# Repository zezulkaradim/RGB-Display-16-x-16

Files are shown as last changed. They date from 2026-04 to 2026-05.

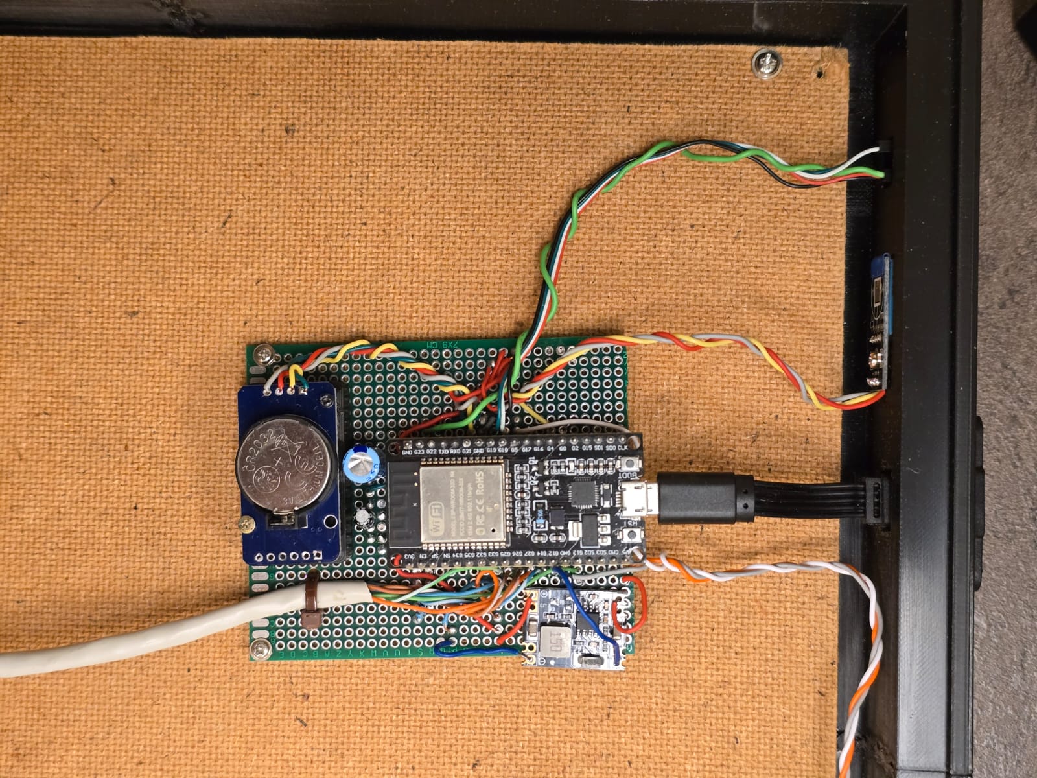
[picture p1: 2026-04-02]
Images/1000010734.jpg

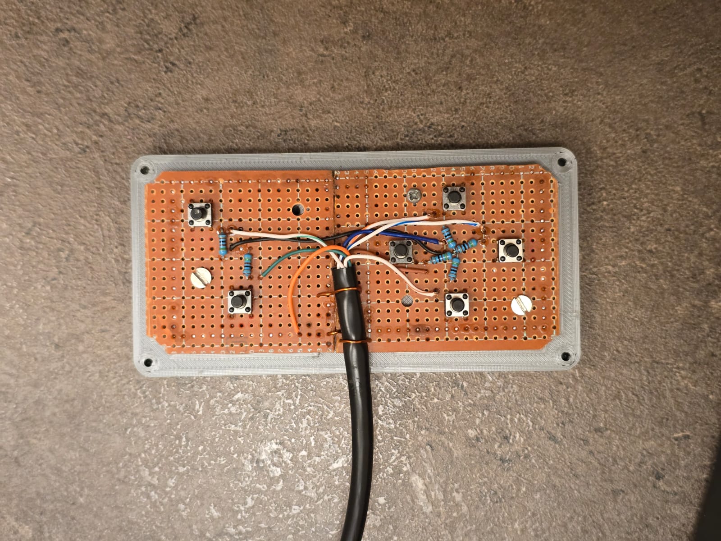
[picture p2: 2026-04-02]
Images/1000010737.jpg

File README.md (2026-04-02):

# RGB-Display-16-x-16

Tato práce se zabývá návrhem a realizací multifunkčního RGB LED displeje o rozměru 16 × 16 pixelů řízeného mikrokontrolerem ESP32. Cílem práce bylo vytvořit samostatné zobrazovací zařízení s více provozními režimy a vlastním způsobem ovládání. Displej je tvořen z adresovatelných LED diod typu WS2812B uspořádaných do čtvercové matice. Součástí řešení je displejové menu, které je ovládáno pomocí externího kabelového ovladače a umožňuje přepínání jednotlivých funkcí zařízení. Implementovány byly digitální hodiny synchronizované přes Wi-Fi s ukládáním času do modulu reálného času DS3231, zobrazení teploty a vlhkosti z čidla DHT11, sada dekorativních animací, hra Had s zobrazením skóre a VU metr využívající digitální mikrofon INMP441. Další funkcí je možnost vzdáleného kreslení na displej prostřednictvím webového rozhraní vytvořeného na platformě ESP32. Výsledkem je vizuálně atraktivní a interaktivní zařízení určené především k dekorativnímu zobrazení, které lze dále rozšiřovat o nové režimy a funkce.

This thesis describes the design and implementation of a multifunctional 16 x 16 RGB LED display controlled by an ESP32 microcontroller. The objective was to develop a standalone display device featuring multiple operating modes and a custom control system. The display consists of WS2812B addressable LEDs arranged in a square matrix. The solution includes a display menu operated via an external wired controller, allowing users to switch between various functions. Implemented features include digital clocks synchronized over Wi-Fi with time storage in a DS3231 real-time clock module, temperature and humidity display using a DHT11 sensor, a set of decorative animations, the game Snake with score tracking, and a VU meter utilizing an INMP441 digital microphone. Additionally, the device supports remote drawing via a web interface. The result is a visually attractive device designed for decorative purposes, with potential for further expansion of functions.

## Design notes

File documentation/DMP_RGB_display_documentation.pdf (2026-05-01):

# Střední Průmyslová Škola Elektrotechnická Ječná

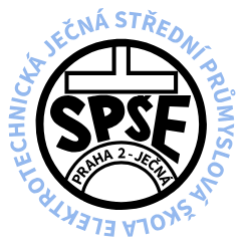
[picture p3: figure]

# DLOUHODOBÁ MATURITNÍ PRÁCE

# RGB displej 16x16

# 2026 Radim Žežulka

# Střední Průmyslová Škola Elektrotechnická Ječná

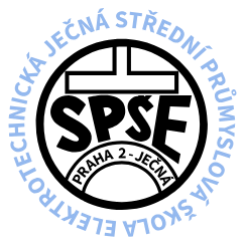
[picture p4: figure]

# DLOUHODOBÁ MATURITNÍ PRÁCE

## RGB displej 16x16

## RGB display 16x16

Autor: | Radim Žežulka
Třída: | E4
Obor: | Elektrotechnika – Elektronické počítačové systémy
Škola: | SPŠE Ječná, Ječná 30, 120 00 Praha 2
Vedoucí práce: | Jan Molič

Oponent práce: Bc. Marek Lavička

Praha, 5.4.2026

## Prohlášení

Prohlašuji, že jsem dlouhodobou maturitní práci (dále jen „DMP“) vypracoval samostatně a

použil jsem pouze prameny a literaturu uvedené v seznamu bibliografických záznamů.

Prohlašuji, že tištěná verze a elektronická verze DMP jsou shodné.

Nemám závažný důvod proti zpřístupňování této práce v souladu se zákonem č. 121/2000 Sb.,

o právu autorském, o právech souvisejících s právem autorským a o změně některých zákonu

(autorský zákon) ve znění pozdějších předpisů.

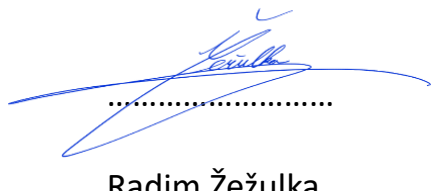
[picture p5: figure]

V Praze dne 7. 4. 2026 | |
| Radim Žežulka

## Poděkování

Chtěl bych poděkovat panu Janu Moličovi za odborné vedení mé maturitní práce. Dále děkuji

Ing. Mgr. Vladimíru Váňovi, CSc., za poskytnutí technických znalostí v oblasti mikroprocesorů

a Ing. Janě Exnerové spolu s Ing. Peterem Budaiem za poskytnutí všeobecných technických

znalostí v oblasti elektrotechniky.

Mé poděkování patří také Mgr. Jindřišce Mrázové za kontrolu jazykové správnosti textu.

Děkuji svému kamarádovi Martinu Loskotovi za pomoc při řešení problémů, na které jsem

v průběhu práce narazil. V neposlední řadě děkuji své rodině za trpělivost a všestrannou

podporu po celou dobu mého studia.

## Anotace

Tato práce se zabývá návrhem a realizací multifunkčního RGB LED displeje o rozměru

16 × 16 pixelů řízeného mikrokontrolerem ESP32. Cílem práce bylo vytvořit samostatné

zobrazovací zařízení s více provozními režimy a vlastním způsobem ovládání. Displej je tvořen

z adresovatelných LED diod typu WS2812B uspořádaných do čtvercové matice. Součástí řešení

je displejové menu, které je ovládáno pomocí externího kabelového ovladače a umožňuje

přepínání jednotlivých funkcí zařízení. Implementovány byly digitální hodiny synchronizované

přes Wi-Fi s ukládáním času do modulu reálného času DS3231, zobrazení teploty a vlhkosti

z čidla DHT11, sada dekorativních animací, hra Had s zobrazením skóre a VU metr využívající

digitální mikrofon INMP441. Další funkcí je možnost vzdáleného kreslení na displej

prostřednictvím webového rozhraní vytvořeného na platformě ESP32. Výsledkem je vizuálně

atraktivní a interaktivní zařízení určené především k dekorativnímu zobrazení, které lze dále

rozšiřovat o nové režimy a funkce.

## Klíčová slova

ESP32, senzory, WS2812B, LED displej, dekorativní osvětlení

## Abstract

This thesis describes the design and implementation of a multifunctional 16 x 16 RGB LED

display controlled by an ESP32 microcontroller. The objective was to develop a standalone

display device featuring multiple operating modes and a custom control system. The display

consists of WS2812B addressable LEDs arranged in a square matrix. The solution includes

a display menu operated via an external wired controller, allowing users to switch between

various functions. Implemented features include digital clocks synchronized over Wi-Fi with

time storage in a DS3231 real-time clock module, temperature and humidity display using

a DHT11 sensor, a set of decorative animations, the game Snake with score tracking,

and a VU meter utilizing an INMP441 digital microphone. Additionally, the device supports

remote drawing via a web interface. The result is a visually attractive device designed

for decorative purposes, with potential for further expansion of functions.

## Keywords

ESP32, sensors, WS2812B, LED display, decorative lighting

## Zadání

Cílem projektu je vytvořit interaktivní 16×16 RGB displej založený na adresovatelných LED

diodách typu WS2812B, řízený mikrokontrolerem ESP32. Projekt má za úkol propojit

zobrazovací plochu s různými senzory a ovládacími prvky tak, aby bylo možné využít displej

k animacím, vizualizacím i jednoduchým hrám.

Součástí zadání je implementace měření teploty a vlhkosti, jejichž aktuální hodnoty bude

displej zobrazovat v reálném čase. Dalším požadavkem je integrace modulu reálného času

(RTC), který umožní zobrazení přesného času a případných časových animací. Pro ovládání

displeje a jeho režimů má být navržen a realizován vlastní ovladač umožňující intuitivní

interakci s celým systémem. Projekt zahrnuje také vytvoření jednoduché hry – konkrétně hry

Had – která bude plně zobrazována na RGB matici a ovládána navrženým ovladačem.

Dále je součástí zadání pokus o implementaci mikrofonu pro vytvoření VU metru reagujícího

na zvukovou intenzitu, ačkoliv tato funkce představuje volitelné rozšíření.

V průběhu zpracování maturitní práce se žák řídí dalšími pokyny vedoucího práce dle potřeby.

## Obsah

8 Bibliografie | Chyba! Záložka není definována.

## 1 Úvod

Při hledání inspirace na internetu mě zaujaly projekty pracující s RGB maticemi, které dokážou

kombinovat funkci informačního panelu a estetického doplňku. Rozhodl jsem se proto vytvořit

vlastní zařízení, které by sloužilo nejen jako originální dekorace do mého pokoje, ale také jako

platforma kombinující různé užitečné nástroje s volnočasovými a interaktivními prvky.

Podobné principy adresovatelných LED systémů můžeme potkávat v každodenním životě.

Od velkoplošných LED billboardů a reklamních ploch až po menší informační panely, jako jsou

například typické svítící kříže u lékáren. Všechna tato zařízení sdílejí společný základ: řízení

stovek světelných bodů pro zobrazení textu a grafiky.

Cílem mé maturitní práce je vytvořit interaktivní 16×16 RGB displej založený

na adresovatelných LED diodách typu WS2812B, řízený mikrokontrolerem ESP32. Projekt má

za úkol propojit zobrazovací plochu s různými senzory a ovládacími prvky tak, aby bylo možné

využít displej k animacím, vizualizacím i jednoduchým hrám.

Výsledné zařízení nabízí pět hlavních provozních režimů, mezi které patří:

- Informační panel: Zobrazení času, teploty a vlhkosti.
- Dekorativní animace: Sada dekoračních animací.
- Hra Had: Plnohodnotná interaktivní hra had.
- Audio vizualizace: FFT VU metr reagující na intenzitu zvuku snímanou mikrofonem.
- Vzdálené kreslení: Možnost kreslení na displej přes webovou stránku.

K ovládání celého systému byl navržen a realizován vlastní kabelový ovladač, který zajišťuje

intuitivní pohyb v menu a interakci s jednotlivými funkcemi. Celý projekt tak představuje celek

propojující hardware, nízko úrovňové programování a síťovou komunikaci.

## 2 Teoretický rozbor

## 2.1 Adresovatelné led diody WS2812b

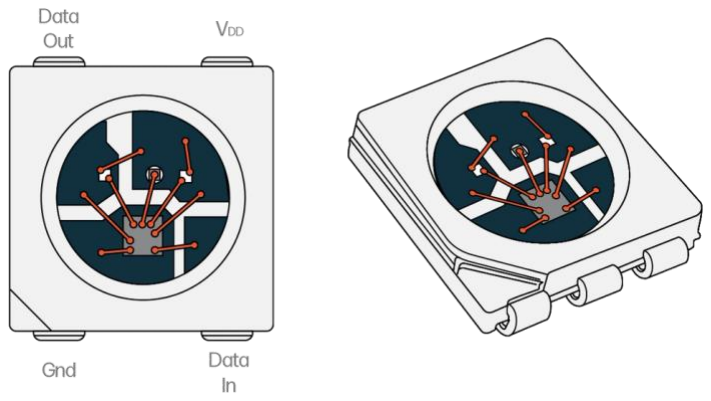
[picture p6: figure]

Obr. 1 - WS2812 LED (převzato z WORLDSEMI, 2024).

WS2812B je adresovatelná led dioda v pouzdře 5050. Každá dioda obsahuje 3 pulsně šířkové

modulátory, které ovládají LED zářiče (červený, zelený a modrý). Dále obsahuje řídící obvod s

vnitřní registrem pro záznam dat, s vnitřními hodinami pro synchronizaci s ostatními WS2812B

diodami a vyhlazujícími obvody, které se starají o konstantní barvu světla a nerušení signálu,

který posílají na Data Out.

K komunikaci používají komunikační protokol One-Wire, který funguje na principu Daisy

Chaining, kde se posílá větší objem dat, a každá dioda si uloží jen svůj podíl v našem případě

3 bajty (jeden bajt na jednu barvu) a zbytek dat pošle dál (další diodě) pomocí pinu Data Out.

Po odeslání informace do všech diod se odešle reset signál, který po krátké pauze (okolo 50 μs)

synchronizovaně nastaví nově zvolenou barvu na všech diodách najednou.

Tyto WS2812B diody lze najít např. v: podsvícení PC komponentů, v chytrých LED páscích

a v reklamních panelech [21, 41].

## 2.2 Aditivní míchání barev

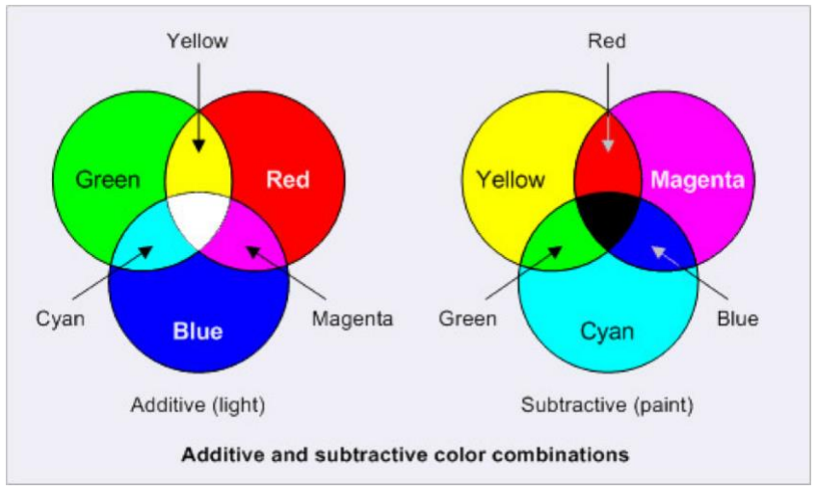
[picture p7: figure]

Obr. 2 - Aditivní a subtraktivní kombinace barev (převzato z MCAD, 2024).

V projektu je využíván princip aditivního míchání barev (RGB), který je typický pro zdroje světla

(emitory). Na rozdíl od subtraktivního míchání (CMYK), které známe z tisku na papír,

kde se barvy odrážejí a jejich sčítáním vzniká černá, u aditivního míchání se světelné toky

jednotlivých barev sčítají. Při plném výkonu všech tří složek vzniká bílé světlo, zatímco

při nulovém výkonu vzniká černá [22, 24].

V softwarové části projektu se pracuje se dvěma způsoby definice barev:

- Model RGB (Red-Green-Blue): Přímo odpovídá hardwaru diody WS2812B. Barva

je definována třemi bajty (0–255), které určují střídu PWM pro červený, zelený a modrý

čip.

- Model HSV (Hue-Saturation-Value): Tento model je výhodnější pro tvorbu plynulých

animací a duhových efektů. Barva je těmito vlastnostmi:

- Hue (Odstín): Určuje polohu barvy na barevném kruhu (0–255 ve FastLED

knihovně).

- Saturation (Sytost): Určuje čistotu barvy (od bílé po plnou barvu).
- Value (Jas): Určuje intenzitu svitu.

## 2.3 Mikrokontroler ESP32

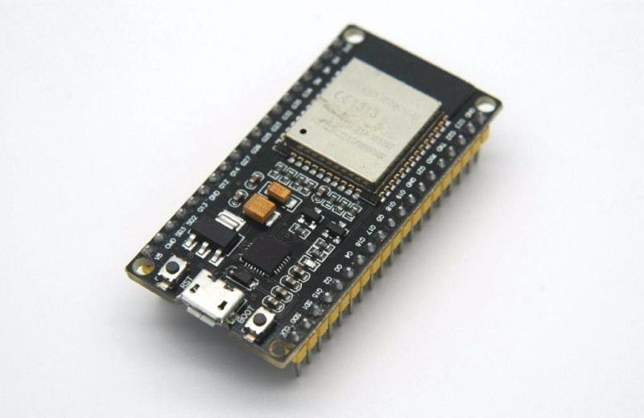
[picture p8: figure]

Obr. 3 - ESP32 Wroom (převzato z Drátek.cz, 2021).

ESP32 je výkonný 32 - bitový mikrokontroler s dvoujádrovým procesorem Xtensa LX6.

V projektu slouží jako hlavní řídicí jednotka, která v reálném čase obsluhuje výpočty pro LED

matici, čtení senzorů a síťovou komunikaci, a byl programován v prostředí Arduino IDE.

Umí komunikovat pomocí sběrnicí UART, SPI, I2C, I2S.

Je často porovnáván se známou alternativou Arduino UNO R3 (a ostatní řady). Avšak ESP32

byla jasná volba, díky osminásobné taktovací frekvenci 240 MHz, větší paměti RAM i Flash

a možnosti pracovat s WI-FI a Bluetooth bez přidaných modulů. Pracuje i na jiném provozním

napětí 3,3 V. Na Arduinech je provozní napětí 5 V, to znamená, že moduly Arduina nemusí být

kompatibilní s ESP32 a při výběru je nutné si na to dát pozor [8, 17, 18].

## 2.4 Digitální přenos zvuku – I2S

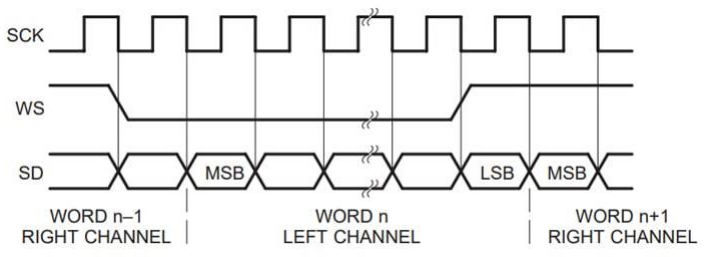
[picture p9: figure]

Obr. 4 - Sběrnice I2S (převzato z All About Circuits, 2026).

Pro realizaci funkce FFT VU metru je v projektu využit digitální mikrofon INMP441,

který s mikrokontrolerem ESP32 komunikuje pomocí protokolu I2S.Na rozdíl od běžných

analogových mikrofonů, které vyžadují předzesilovač a ADC převodník, I2S mikrofon odesílá

data již v digitální podobě, což eliminuje šum a rušení vznikající na analogových cestách [5].

I2S je sériová sběrnice navržená speciálně pro přenos digitálních audio dat mezi integrovanými

obvody. Protokol odděluje hodinový signál od datových toků, což minimalizuje časové

zkreslení. K propojení jsou zapotřebí tři hlavní vodiče:

1. SCK (Serial Clock): Bitové hodiny, které určují rychlost přenosu jednotlivých bitů.
2. WS (Word Select): Určuje, zda aktuálně přenášená data patří levému nebo pravému

zvukovému kanálu (uzemněním tohoto vodiče jsem nastavil pouze levý kanál).

3. SD (Serial Data): Samotná audio data přenášená v digitální podobě.

Po přijmutí dat mikrokontrolerem je aplikována rychlá Fourierova transformace (FFT),

která převede časový signál na frekvenční spektrum. Výsledek je poté zobrazen na displeji [6].

## 2.5 Sběrnice I2C

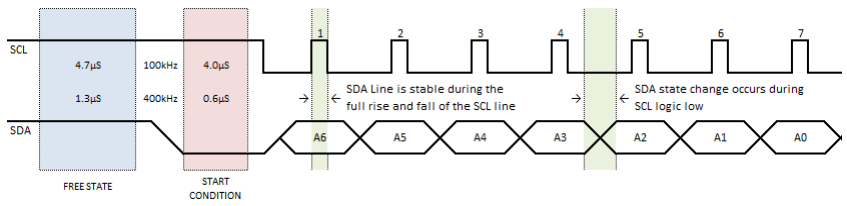
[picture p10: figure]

Obr. 5 - Sběrnice I2C (převzato z HIENYSCH, 2015).

I2C je synchronní, sériová sběrnice typu Master – Slave, která k přenosu dat využívá pouze dva

vodiče. V tomto projektu zajišťuje stabilní komunikaci mezi mikrokontrolerem ESP32 (Master)

a modulem reálného času DS3231 (Slave).

Sběrnice se skládá ze dvou signálových linek:

- SDA (Serial Data): Linka pro obousměrný přenos dat.
- SCL (Serial Clock): Hodinový signál, který určuje rychlost přenosu.

Hlavní výhodou I2C je možnost připojit na stejné dva vodiče teoreticky až 127 různých zařízení.

Každá periferie má svou pevnou 7bitovou adresu (DS3231 má adresu 0x68).

ESP32 vyšle na sběrnici signál start a následně adresu zařízení, se kterým chce mluvit.

Toto zařízení potvrdí, že signál příkaz obdrželo. Ostatní moduly na sběrnici zprávu ignorují.

Po potvrzení adresy následuje samotný přenos dat.

V mém projektu ESP32 v pravidelných intervalech dotazuje modul DS3231, na aktuální stav

vnitřních čítačů času, získaný čas zobrazuje. Při synchronizaci s NTP serverem odesílá ESP32

po I2C sběrnici nová data k zápisu do paměti modulu, čímž DS3231 seřídí na aktuální čas

(krystalový oscilátor, který udává časový průběh v DS3231 není dokonalý a po delší době

bez synchronizace s NTP serverem by se mohl odchýlit od reálného času) [4].

## 2.6 Síťové protokoly NTP, HTTP

NTP (Network Time Protocol) slouží k synchronizaci vnitřního času zařízení s časovými servery

na internetu. ESP32 odešle požadavek na UDP port 123. Server odpoví časovou značkou

v koordinačním světovém čase (UTC). Po spuštění se ESP32 připojí k Wi-Fi, získá aktuální čas

přes NTP, připočte posun časového pásma a tento údaj zapíše do modulu DS3231 (RTC). Tím

je zajištěno, že hodiny běží přesně i po ztrátě konektivity.

HTTP (Hypertext Transfer Protokol) je základem komunikace mezi webovým prohlížečem

a ESP32. V režimu vzdáleného kreslení běží na ESP32 jednoduchý web server. Ten odesílá

JavaScript kód do telefonu či počítače uživatele a následně přijímá HTTP požadavky s daty

o barvách a souřadnicích pixelů, které má displej vykreslit [3,12].

## 2.7 Provozní režimy Wi-Fi

V projektu jsou využity oba základní režimy Wi-Fi, které ESP32 nabízí, přičemž každý slouží

k jinému účelu:

Režim STA (Station Mode)zde se ESP32) chová jako běžný telefon, který se připojuje k existující

Wi-Fi síti (routeru). Tento režim je aktivní při startu zařízení pro spojení s NTP serverem

a stažení přesného času.

Režim AP (Soft Access Point) zde ESP32 vytvoří svou vlastní Wi-Fi síť s vlastním názvem

a heslem. ostatní zařízení se připojují přímo k němu. tento režim je využit pro vzdálené

kreslení. uživatel se připojí k Wi-Fi síti displeje a v prohlížeči zadá IP adresu (192.168.4.1),

čímž se dostane k ovládacímu rozhraní bez nutnosti mít v dosahu jiný router [1, 13].

## 3 Schémata zapojení

## 3.1 Schéma zapojení

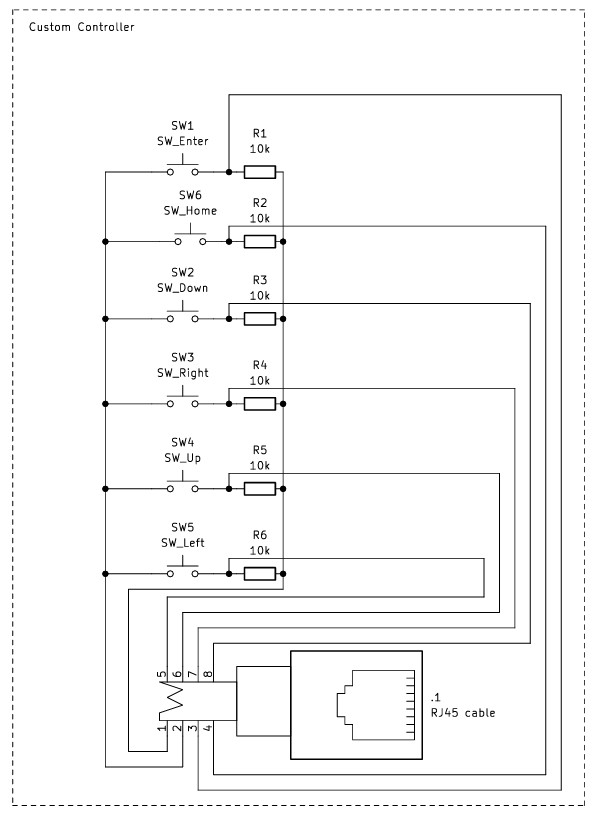
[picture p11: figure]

Obr. 6 - Schéma zapojení vlastního ovladače (autor, 2026).

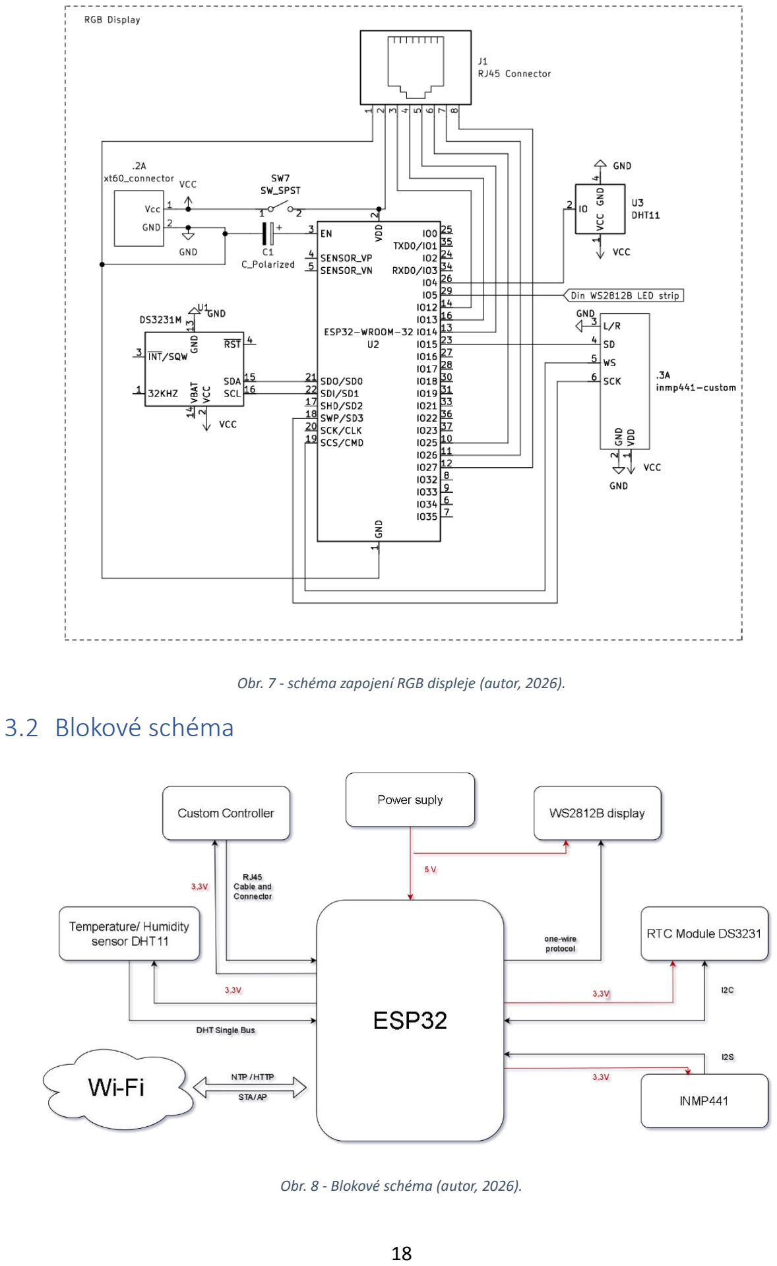
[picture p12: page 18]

Obr. 7 - schéma zapojení RGB displeje (autor, 2026).

## 3.2 Blokové schéma

Obr. 8 - Blokové schéma (autor, 2026).

## 3.3 Schéma zapojení LED matice

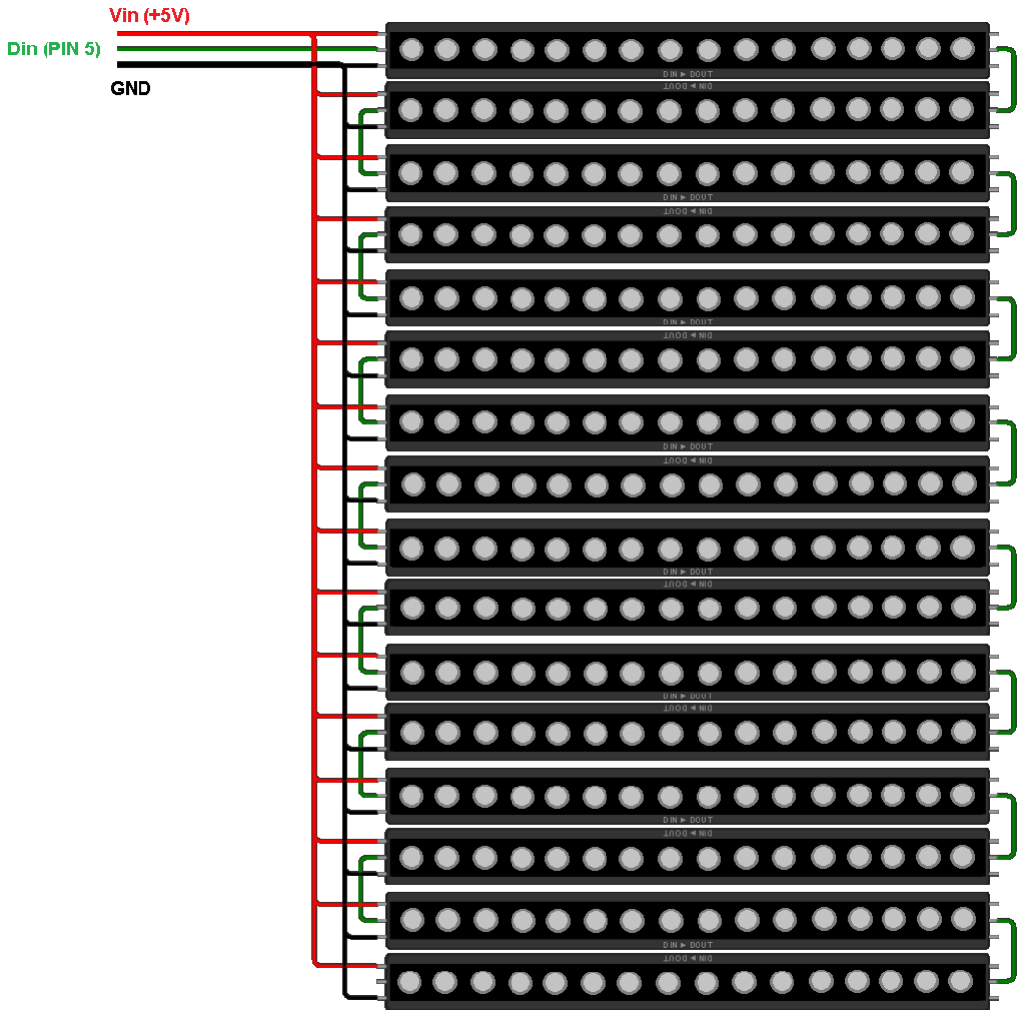
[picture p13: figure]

Obr. 9 - schéma zapojení LED matice (autor, 2026).

## 4 Hardwarové řešení

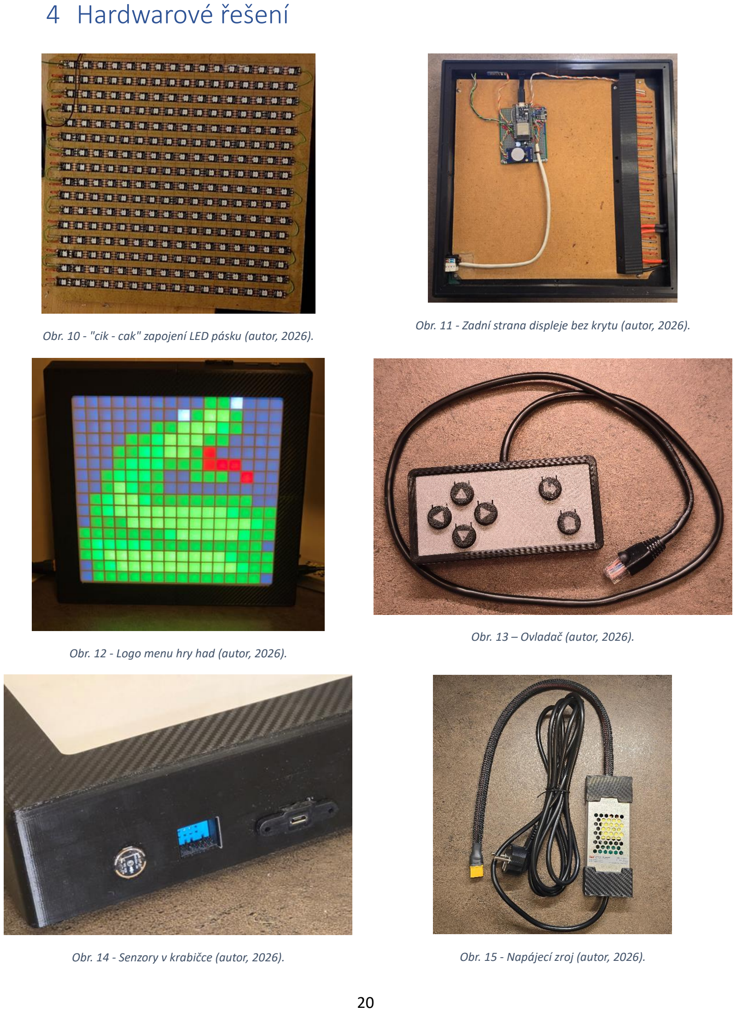
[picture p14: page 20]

Obr. 10 - "cik - cak" zapojení LED pásku (autor, 2026).

Obr. 11 - Zadní strana displeje bez krytu (autor, 2026).

Obr. 12 - Logo menu hry had (autor, 2026).

Obr. 13 – Ovladač (autor, 2026).

Obr. 14 - Senzory v krabičce (autor, 2026). | Obr. 15 - Napájecí zroj (autor, 2026).

Všechny plastové komponenty zařízení byly modelovány v CAD softwaru Autodesk Fusion 360

a následně vytisknuty pomocí 3D tiskárny Bambulab P1S (většina součástek byla modelována

do čtyř částí, kvůli nedostatku místa na podložce tiskárny). Jako materiál byl zvolen filament

PETG, který projektu dodává potřebnou tepelnou a mechanickou odolnost pro dlouhodobý

provoz [34, 35].

## 4.1 Konstrukce zobrazovacího panelu

Zobrazovací panel tvoří základna z lakované dřevovláknité desky (sololitu) s osazenými

LED pásky typu WS2812B v hadovitém uspořádání, na které dosedá 3D tištěná mřížka definující

jednotlivé pixely. Jako difuzor je použit ustřižený papír formátu A3, který je proti vnějšímu

poškození chráněn čirým plexisklem o tloušťce 2 mm.

## 4.2 Konstrukce napájecí části

Jako zdroj napájení byl zvolen průmyslový spínaný zdroj LEDMAX 5 V s výkonem 75 W

a maximálním proudem 15 A, který je pro bezpečnost opatřen vlastním 3D tištěným krytem

svorkovnice. Propojení se zobrazovacím panelem zajišťuje konektor XT60, jenž disponuje

dostatečnou proudovou rezervou. Z estetických důvodů je přívodní kabeláž chráněna černým

textilním opletem.

## 4.3 Konstrukce ovladače

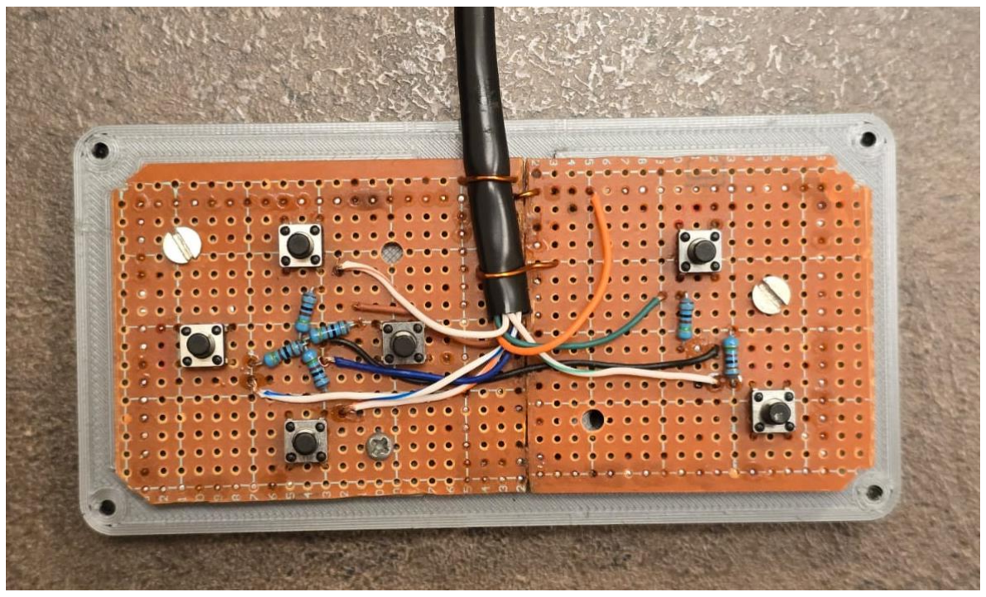
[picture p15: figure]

Obr. 16 - Vnitřní zapojení ovladače (autor, 2026).

Ovladač je umístěn v 3D tištěné krabičce a jeho vnitřní zapojení je na univerzální prototypové

desce (perfboard). Toto řešení bylo zvoleno pro okamžitou dostupnost v domácích

podmínkách.

Ovládací panel tvoří celkem šest mikrospínačů, z nichž každý je doplněn o pull-down rezistor

s odporem 10 kΩ. Propojení s hlavní jednotkou zajišťuje UTP (RJ45) kabel. Volba tohoto řešení

padla po neúspěšném několikadenním hledání alternativ, protože tento kabel má potřebných

osm vodičů (napájení, zem a šest linek pro tlačítka), což z něj činí nejdostupnější

a nejefektivnější variantu pro naše použití.

## 4.4 Konstrukce displeje

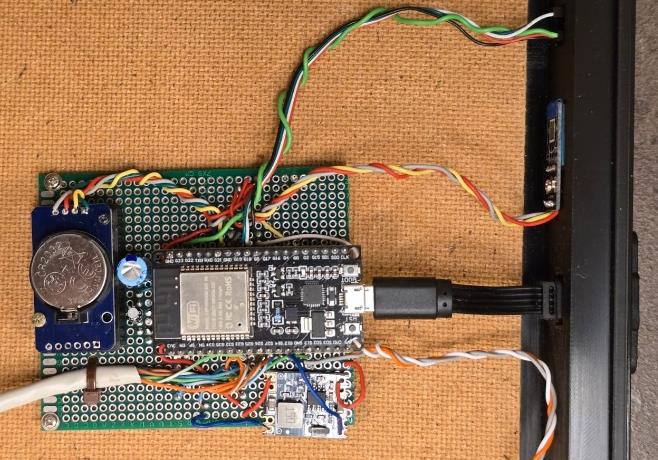
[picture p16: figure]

Obr. 17 - Vnitřní zapojení displeje (autor, 2026).

Vnitřní elektronika displeje byla rovněž realizována na univerzální prototypové desce

(perfboard), a to především pro rychlost montáže a snadnou modifikaci zapojení během

vývoje. Jednotlivé senzory byly záměrně vyvedeny na vnější strany šasi, aby se zamezilo

ovlivnění měřených hodnot (zejména teploty) zbytkovým teplem generovaným LED maticí

uvnitř skříně. Pro usnadnění správy softwaru byl do konstrukce integrován 5 cm prodlužovací

Mikro USB kabel vyvedený na boční panel, který umožňuje aktualizaci řídicího kódu bez

nutnosti sundávání zadního krytu zařízení.

## 5 Popis použitých součástek

## 5.1 WS2812B LED pásek

Pro konstrukci zobrazovací matice byl vybrán digitální adresovatelný pásek osazený čipy

WS2812B. Hlavním důvodem pro volbu tohoto typu LED pásku je jeho časté použití

v podobných projektech, na které jsem na internetu narazil. Na internetu je také široká škála

návodů a otevřených knihoven, které využívají právě čip WS2812B, ze kterých jsem čerpal.

Další důvodem bylo, že pásek funguje na logické úrovni 3,3 V navzdory výrobcem uvedené

úrovni 5 V [11].

- Model: WS2812B 5050 5 m 300 IP20
- Napájecí napětí: 5 V DC
- Počet diod: 300 LED / 5 m
- Spotřeba energie: 11 W/m
- Stupeň ochrany: IP20
- Úhel svícení: 120°

## 5.2 ESP32 DevKit

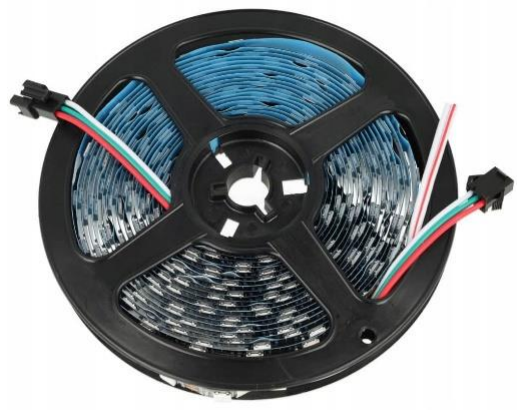
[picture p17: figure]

Zvolený modul představuje výkonnou alternativu k platformě Arduino, oproti které nabízí

řádově vyšší výpočetní výkon a integrovanou bezdrátovou konektivitu. Ideální poměr

cena/výkon, masivní komunitní podpora a schopnost obsloužit webový server paralelně

s řízením LED matice díky dual-core byli hlavními důvody pro výběr právě tohohle

mikroprocesoru [8].

- Procesor: Dual-core Xtensa 32-bit LX6 (240 MHz).
- Konektivita: Wi-Fi 802.11 b/g/n a Bluetooth (v4.2 BR/EDR/BLE).
- Paměť: 520 KB SRAM, 4 MB Flash.
- Napájení: 5 V (přes USB nebo pin Vin), pracovní napětí logiky 3,3 V.
- Periferie: 12-bit ADC, 2× I2S, I2C, UART, PWM.

Obr. 18 - WS2812b LED pásek (převzato z ALLEGRO.CZ, 2026).

## 5.3 DS3231 modul

Modul zajišťuje uchování a běh přesného času i při odpojení hlavního napájení zařízení.

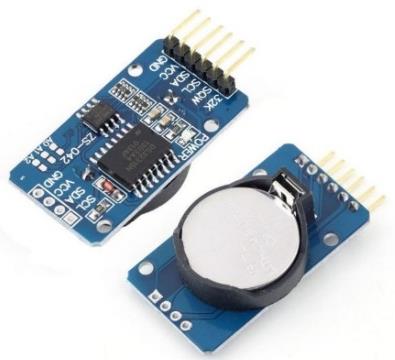
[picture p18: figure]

Původně zvažovaná levnější varianta DS1302 nebyla vybrána z důvodu nízké přesnosti a vysoké

tepelné závislosti, což by způsobovalo rozcházení hodin [16].

- Přesnost: ±2 ppm (odchylka cca 1 minuta za rok).
- Senzor: Integrovaný teplotní senzor pro kompenzaci

krystalu.

- Záloha: Slot pro baterii CR2032.
- Komunikace: Sběrnice I2C.

## 5.4 DHT11 modul

Tento modul byl zvolen především pro svou kompaktnost a snadnou mechanickou montáž

do šasi zařízení. I přes nižší přesnost a omezený měřicí rozsah oproti dražším alternativám je

pro účely pokojového teploměru naprosto dostačující, jelikož se nepředpokládá provoz

v extrémních podmínkách [7, 15].

- Rozsah měření teploty: 0 až 50 °C

(přesnost ±2 °C).

- Rozsah měření vlhkosti: 20 až 90 % RH

(přesnost ±5 %).

- Komunikace: Single-bus

Obr. 19 - DS3231 RTC modul (prevzato z GME.CZ, 2026).

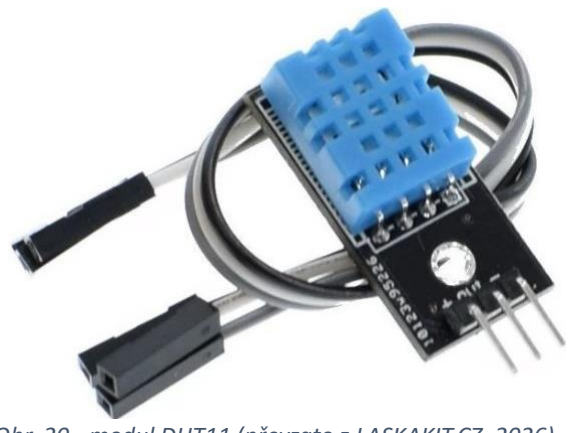
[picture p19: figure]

Obr. 20 - modul DHT11 (převzato z LASKAKIT.CZ, 2026).

## 5.5 INMP411 mikrofon

Původně testovaný modul GY-4466 vykazoval při náhlých změnách akustického tlaku (přechod

z ticha do vysoké hlasitosti) softwarovou chybu v podobě nestabilního vzorkování, kterou

se nepodařilo odstranit. Na základě rešerše a úspěšných komunitních projektů byl proto zvolen

digitální mikrofon INMP441, který tyto problémy díky přímému digitálnímu výstupu eliminuje

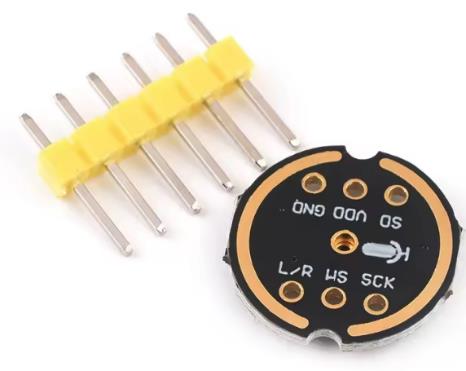
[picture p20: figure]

[14, 19].

- Rozhraní: I2S.
- Typ snímače: Všesměrový MEMS mikrofon s

vysokým SNR.

- Frekvenční rozsah: 60 Hz až 15 kHz.
- Napájení: 3,3 V.
- Zpracování: Integrovaný 24bitový ADC přímo v

pouzdře.

## 5.6 Napájecí zdroj

Pro napájení celého systému byl zvolen průmyslový spínaný zdroj LEDMAX s výstupním

napětím 5 V a maximálním proudem 15 A. Tato volba odpovídá vypočtenému špičkovému

odběru LED matice při plném jasu bílé barvy s bohatou rezervou, pro napájení ostatních

komponentů [9].

- Výstupní výkon: 75 W.
- Výstupní napětí: 5 V.
- Maximální proud: 15 A.
- Vstupní napětí: 100–240 V AC.
- Ochrany: Ochrana proti zkratu, přetížení a

přepětí.

Obr. 21 - digitální mikrofon INMP441 (převzato z ELECTROPEAK.COM, 2026).

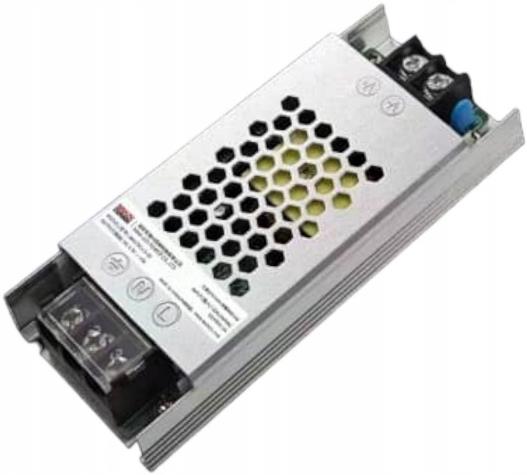
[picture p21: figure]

Obr. 22 - Napájecí zdroj LEDMAX 75 W (převzato z ALLEGRO.CZ, 2026).

Výpočet maximálního oddběru proudu displeje:

Maximální výkon 1 metru LED pásku je prodejcem uváděn jako:

Pmetr = 11 W/m

Jeden metr takového LED pásku obsahuje 60 diod. Platí tedy že:

nmetr = 60

Výkon 1 LED diody lze vypočítat jako:

Pd =

Pmetr

nmetr

=

11
60 W ≅ 183 mW

Pro maximální odběr proudu jedné diody, při vstupním napětí Uin = 5 V platí:

Idmax =

Pd

Uin

=

183 ∙ 10⁻³ W
5 V

≅ 36,6 mA

Následně stačí vypočítat maximální proud odebýraný displejem při plném počtu LED ndisplej =

256 nastaveném na bílou barvu se 100 % jasu.

Imax = ndisplej ∙ Idmax = 256 ∙ 36,6 ∙ 10⁻³A = 9,37 A

## 6 Softwarová realizace

## 6.1 Vývojové prostředí a jeho nastavení

Programování probíhalo v prostředí Arduino IDE s nainstalovanou podporou pro čipy ESP32.

Tato platforma byla zvolena pro svou přehlednost a rozsáhlou knihovnu hotových řešení

pro použité senzory [17, 18].

- Deska: ESP32 Dev Module.
- Frekvence CPU: 240 MHz.
- Rychlost nahrávání: 921 600 bps.

## 6.2 Použité knihovny

Pro zajištění funkčnosti všech systémů byly využity následující knihovny, které umožňují

efektivní komunikaci s hardwarem:

- FastLED.h (Daniel Garcia, Mark Kriegsman): Knihovna pro ovládání LED pásků [25].
- OneButton.h (Matthias Hertel): Zpracování vstupů z tlačítek [32].
- WiFi.h & WebServer.h (Espressif Systems): Knihovny zajišťující připojení k síti [33].
- Time.h (Michael Margolis): Knihovna pro práci s časem [26].
- DHT.h(Adafruit): Knihovna pro čtení ze senzoru DHT11 [28].
- RTClib.h (Adafruit): Knihovna pro komunikaci se modulem DS3231 [29].
- arduinoFFT.h (Enrique Condes): Provádí rychlou Fourierovu transformaci [30].
- driver/i2s.h (Espressif Systems): Knihovna pro mikrofon INMP441 [31].
- ArduinoJson.h (Benoît Blanchon): Knihovna pro práci s formátem JSON [27].

## 6.3 Logika menu

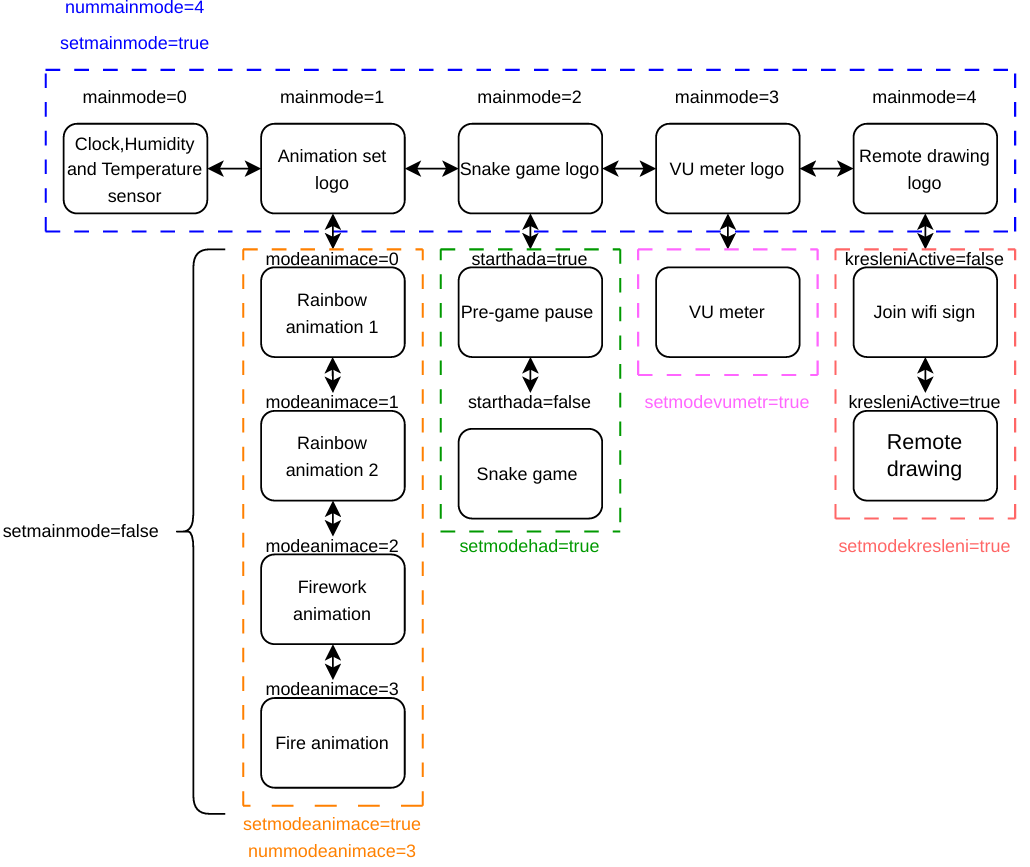
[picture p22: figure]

Obr. 23 - Diagram menu (autor, 2026).

Systém pracuje s globální proměnnou mainmode, která určuje aktuálně vybrané číslo režimu.

Pro snadnou rozšiřitelnost projektu je zavedena konstanta nummainmode, která definuje

celkový počet dostupných módů a umožňuje tak systém jednoduše modulovat. Stav, zda se

uživatel nachází v hlavní nabídce, nebo uvnitř konkrétního podprogramu, hlídá logická

proměnná setmainmode.

V hlavní smyčce loop() se neustále aktualizuje stav tlačítek pomocí metody tick(). Na základě

stisku se spouštějí následující funkce:

- clickplay(): Tato funkce slouží k potvrzení výběru v hlavním menu. Obsahuje sadu

podmínek, které při splnění (setmainmode == true) deaktivují hlavní menu a inicializují

příslušný podprogram (např. setmodeanimace nebo setmodehad).

- clickhome(): Plní funkci návratu. Pokud je aktivní jakýkoliv podrežim, funkce ho ukončí,

nastaví setmainmode zpět na true a provede kompletní vyčištění proměnných

ukončeného podprogramu. Tím se předejde chybám při opětovném vstupu do módu.

- clickup() / clickdown(): Tyto funkce v jsou režimu menu neaktivní, ale v módu hry Had

slouží k ovládání směru.

- clickright() / clickleft(): Zajišťují listování v hlavním menu tím, že přičítají nebo odečítají

hodnotu k mainmode. Také ovládají horizontální pohyb ve hrách.

## 6.4 Hodiny a záloha přes RTC

Tato část softwaru zajišťuje zobrazování času a dat o vlhkosti a teplotě okolí displeje na LED

matici.

Využití funkce manageWiFiNonBlocking() je klíčové pro plynulý chod systému. Namísto

klasického čekání na spojení, které by zastavilo veškeré animace, program v pravidelných

intervalech pouze kontroluje stav. Pokud je Wi-Fi připojena, synchronizuje vnitřní čas s NTP

serverem. Pokud ne, plynule přechází na čtení dat z hardwarového modulu RTC DS3231. Tím

je zaručeno, že hodiny nikdy neukážou nepřesný čas.

Čas i data ze senzoru DHT11 jsou před zobrazením matematicky rozkládány na jednotlivé cifry.

Tento rozklad (např. hodina1 = hodina / 10; hodina2 = hodina % 10;) umožňuje funkci

vykreslicislo() adresovat konkrétní vzory čísel na přesné souřadnice matice.

Zobrazení není statické, ale využívá vnitřní počítadlo pocetsekundDHT, které

v desetisekundových cyklech přepíná spodní část displeje:

- 0–5 sekund: Zobrazuje aktuální teplotu doprovázenou symbolem stupně (°C).
- 5–10 sekund: Displej se v dané oblasti vymaže a vykreslí vlhkost se symbolem %.
- Každou sekundu: Dvojtečka mezi hodinami a minutami mění svůj stav každou sekundu.

V levém horním rohu je jeden pixel nabývající jedné ze dvou barev. Tento pixel slouží jako

ukazatel stavu sítě:

- Zelená: Displej je připojený k Wifi a čas je synchronizovaný s časem z NTP.
- Červená: Displej není připojený k Wifi a čas je převzatý z RTC modulu.

## 6.5 Hra Had

Tato část softwaru se týká hry had (jeho pohyb, růst, detekce kolizí a zaznamenávání bodů).

Tělo hada je uloženo v poli struktur had[], kde každý prvek obsahuje souřadnice x a y. Hlavní

mechanikou je posun těla: při každém kroku se souřadnice každého článku přepíší

souřadnicemi článku předchozího (od konce k hlavě), čímž vzniká pohyb.

- Obtížnost: Rychlost pohybu se zrychluje v závislosti na počtu bodů.
- Vykreslování: Články těla vykreslovány střídavě dvěma odstíny zelené.

Generování jablka zajišťuje funkce generujjablko(). Ta využívá generátor náhodných čísel

a cyklus dowhile k ověření, že se jablko neobjeví přímo v těle hada. Pokud hlava narazí

na souřadnice jablka, délka hada je prodloužena a posun těla proběhne s novým článkem.

Program v každém kroku provádí tři typy kontrol:

- Kolize s vlastním tělem: Kontroluje, zda se její budoucí souřadnice hlavy se neshoduje

s jakýmkoliv článkem hada.

- Kolize se zdí: Hranice matice (0–15) jsou pevně dány. Pokud had narazí do okraje,

aktivuje se stav prohry.

Při prohře se zastaví hra a spustí se vizuální sekvence youlosthad(). Ta zahrnuje nápis

„YOU LOST“ (vytvořený přímým adresováním pixelů jako pixel-art) a zobrazení konečného

skóre.

Pohyb je rozdělen do funkcí haddoprava(), haddoleva(), hadnahoru() a haddolu(). Každá funkce

obsahuje logiku pro aktualizaci hlavy v daném směru. Důležitým prvkem je podmínka,

která blokuje možnost otočení hada o 180°, aby nedošlo k okamžité kolizi sama se sebou.

## 6.6 Zvuková vizualizace (VU metr)

VU metr vyžaduje plynulý tok dat z mikrofonu a jejich okamžitou matematickou analýzu.

Pro tento účel byl využit kód z části převzatý z projektu WLED (Andrew Tuline), který byl

optimalizován pro potřeby 16×16 displeje a digitálního mikrofonu INMP441.

Klíčovou vlastností mikrokontroleru ESP32 je jeho dvoujádrová architektura. Díky tomuto

rozdělení nedochází k trhání animací ani při vysoké výpočetní náročnosti FFT.

- Jádro 0: Vyhrazeno výhradně pro funkci FFTcode(). Zde probíhá čtení vzorků z I2S

sběrnice a výpočet Rychlé Fourierovy transformace.

- Jádro 1: Zajišťuje chod zbytku programu.

Vzorky zvuku jsou odebírány frekvencí 10 240 Hz. Knihovna arduinoFFT.h transformuje signál

z časové domény na 16 frekvenčních pásem.

- Post-processing: Protože lidské ucho vnímá frekvence logaritmicky, jsou surová data

upravena a je odfiltrován tichý šum z pozadí.

- Vyhlazení: Aby sloupce na displeji nepříjemně neskákaly, je použita funkce pro

vyhlazení prevFFTValue(), která míchá aktuální hodnotu s předchozí v poměru 3:1.

Samotná funkce vumetr() převádí vypočtené hodnoty na vizuální efekt:

- Vykreslování barev: Každý ze 16 sloupců má svou barvu definovanou v barevném

spektru HSV.

- Indikace špiček: Funkce drawWhitePeak() vykresluje bílý bod na nejvyšší dosažené

úrovni každého sloupce.

- Efekt pádu: Pomocí funkce decayPeaks() bílé špičky pomalu padají dolů.

## 6.7 Vzdálené kreslení

Tato část softwaru promění LED displej v interaktivní plochu ovládanou přes webové rozhraní.

Jelikož je hlavní náplní práce hardware a nízko úrovňové programování v C++, a zároveň je

funkce vzdáleného kreslení funkce navíc (nebyla součástí zadání). Byla samotná webová

stránka pro zjednodušení vygenerována pomocí umělé inteligence. Stránka je napsána

v HTML5 a JavaScriptu a je uložena přímo v programové paměti ESP32.

Rozhraní obsahuje plátno o velikosti 16×16 pixelů, výběr barvy, různé velikosti štětce

(1×1 až 5×5) a funkci gumy.

Při každém pohybu po plátně odesílá prohlížeč na pozadí požadavky ve formátu JSON, které

obsahují souřadnice pixelů a jejich barvu.

Po spuštění módu kreslení se ESP32 odpojí od Wi-Fi a vytvoří vlastní síť s názvem RGB-DISPLAY.

Funkce kresleni() inicializuje server a definuje tzv. handlery pro různé URL adresy:

- /: Odešle uživateli HTML stránku.
- /update: Přijímá JSON data s barvami pixelů.
- /clear: Vymaže celou kresbu.

Zpracování příchozích dat probíhá pomocí knihovny ArduinoJson.h. Funkce handleUpdate()

přijímá přijatý balíček dat a zapisuje barvy do pomocné paměti ledBuffer.

Aby nedocházelo k blikání displeje při každém přijatém paketu, kód využívá oddělenou paměť

(ledBuffer). Skutečný zápis do LED pásku probíhá jednou za 50 ms.

Funkce stopKresleni() zajišťuje správné vypnutí serveru a přepnutí Wi-Fi modulu zpět

do režimu sběru času z NTP.

## 6.8 Logika Pixel-Artu a mapování souřadnic

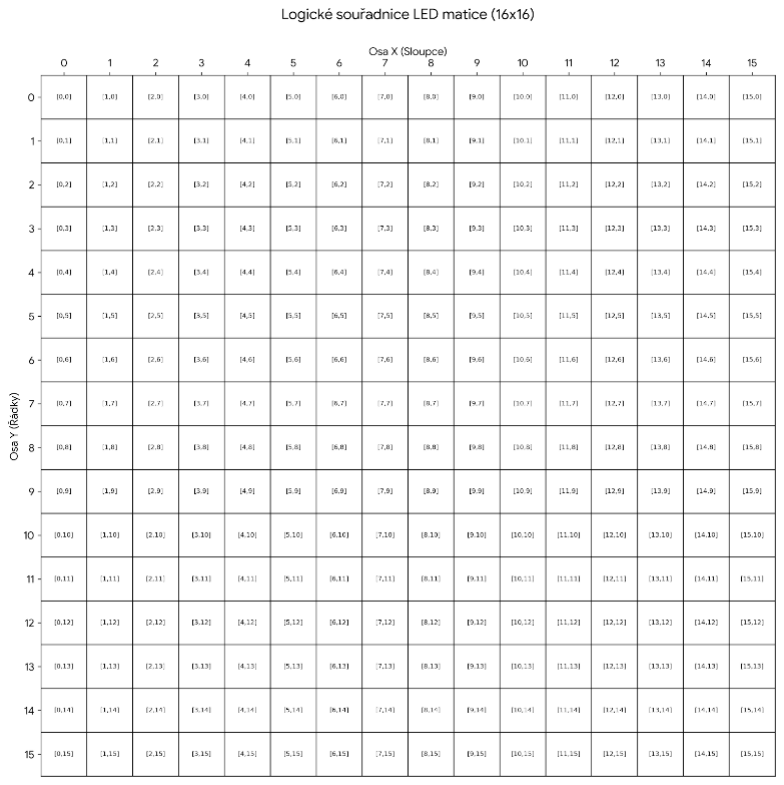
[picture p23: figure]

Základním stavebním kamenem veškeré grafiky v tomto projektu je schopnost adresovat

konkrétní diodu na matici pomocí standardních kartézských souřadnic [x, y]. Vzhledem k tomu,

že fyzický LED pásek je uvnitř panelu poskládán v hadovitém uspořádání, bylo nutné vytvořit

funkci, která toto uspořádání přepočítá na číslo od 0 do 255.

K tomuto účelu slouží funkce XY(). Její algoritmus využívá operaci modulo (zbytek po dělení),

aby rozlišil směr zápisu v jednotlivých řádcích:

- Sudé řádky (y % 2 == 0): LED diody jsou zapojeny zleva doprava. Výpočet indexu je

přímý: (y ∙ WIDHT) + x.

- Liché řádky (y % 2 != 0): LED diody jsou zapojeny zprava doleva. Aby software stále

vnímal levou stranu jako počátek osy x, musí být index v těchto řádcích zrcadlen:

(y ∙ WIDTH) + (WIDTH − 1 − x)

Obr. 24 - Ukázka mapování souřadnic (autor, 2026; vizualizováno pomocí AI Google Gemini).

## 7 Vyhodnocení

Cílem této maturitní práce bylo navrhnout a vlastnoručně sestavit inteligentní RGB

zobrazovací panel o rozlišení 16×16 pixelů, který by kombinoval funkci estetického doplňku

s praktickým využitím. Mohu konstatovat, že se projekt podařilo dotáhnout do úspěšného

konce a všechny body zadání byly splněny. Zařízení zobrazuje přesný čas synchronizovaný přes

internet, měří okolní teplotu a umožňuje hraní her i hudební vizualizaci. Nad rámec zadání

se mi podařilo implementovat také funkci vzdáleného kreslení, díky které může uživatel

v reálném čase ovládat displej přes webové stránky.

Při prototypování jsem narazil na mnoho překážek, přičemž největší technickou výzvu

představovala zvuková vizualizace. Při použití původního analogového mikrofonu

se v softwaru naskytovala chyba, která při náhlé změně frekvencí způsobovala problikávání

celého displeje. Tento problém se mi podařilo definitivně odstranit až přechodem na digitální

mikrofon INMP441 společně s inspirací z kódu od autora s-marley a jeho projektem

ESP32- INMP441-Matrix-VU na platformě GitHub.

Ačkoliv je panel v tuto chvíli plně funkční, vidím v něm velký potenciál pro další rozvoj. Projekt

je navržen modulárně, takže by v budoucnu nebyl problém přidat další herní módy, jako je

například Tetris. Při pohledu na konstrukční zpracování je patrné, že zařízení má v určitých

částech spíše charakter funkčního prototypu než finálního komerčního produktu, a beru

to jako oblast, na které by se dalo v budoucnu v rámci další verze určitě zapracovat.

## 8 Seznam zdrojů

## 8.1 Webové zdroje

[1] ELECTRONICWINGS. ESP32 Wi-Fi Basics Getting Started. Online. Dostupné z:

https://www.electronicwings.com/esp32/esp32-wi-fi-basics-getting-started. [cit.

2026-04-07].

[2] GM ELECTRONIC. ZS-042 modul RTC, I2C a 32kb flash. Online. Dostupné z:

https://www.gme.cz/v/1507874/zs-042-modul-rtc-i2c-a-32kb-

flash?srsltid=AfmBOoprWULbbFY-yvjoF98u6hlcgiXIXyazCTnIr2VTWcsL3vwfv9IC. (https://www.gme.cz/v/1507874/zs-042-modul-rtc-i2c-a-32kb-flash)

[cit. 2026-04-07].

[3] Hypertext Transfer Protocol [heslo]. Online. In: Wikipedie: Otevřená encyklopedie.
19. 09. 2025. Dostupné z:

https://cs.wikipedia.org/wiki/Hypertext_Transfer_Protocol. [cit. 2026-04-07].

[4] I²C [heslo]. Online. In: Wikipedie: Otevřená encyklopedie. 20. 07. 2025. Dostupné

z: https://cs.wikipedia.org/wiki/I%C2%B2C. [cit. 2026-04-07].

[5] I²S [heslo]. Online. In: Wikipedie: Otevřená encyklopedie. 30. 07. 2025. Dostupné

z: https://cs.wikipedia.org/wiki/I%C2%B2S. [cit. 2026-04-07].

[6] KEIM, Robert. Introduction to the I2S Interface. Online. In: All About Circuits. 04.
03. 2020. Dostupné z: https://www.allaboutcircuits.com/technical-

articles/introduction-to-the-i2s-interface/. (https://www.allaboutcircuits.com/technical-articles/introduction-to-the-i2s-interface/) [cit. 2026-04-07].

[7] LASKAKIT. ASAIR air temperature and humidity sensor DHT11, module. Online.

Dostupné z: https://www.laskakit.cz/en/arduino-senzor-teploty-a-vlhkosti-

vzduchu-dht11--modul/. (https://www.laskakit.cz/en/arduino-senzor-teploty-a-vlhkosti-vzduchu-dht11--modul/) [cit. 2026-04-07].

[8] LASKAKIT. IoT ESP-WROOM-32 2.4GHz Dual-Mode WiFi+Bluetooth rev.1, CP2102.

Online. Dostupné z: https://www.laskakit.cz/en/iot-esp-32s-2-4ghz-dual-mode-

wifi-bluetooth-rev-1--cp2102/. (https://www.laskakit.cz/en/iot-esp-32s-2-4ghz-dual-mode-wifi-bluetooth-rev-1--cp2102/) [cit. 2026-04-07].

[9] LEDMAXPL. Napájecí zdroj LEDMAX 75W 15A 5V. Online. Dostupné z:

https://allegro.cz/produkt/napajeci-zdroj-ledmax-75w-15a-5v-71bc9f56-62d9-

4d03-9451-066455f0ef41?offerId=15003230425. (https://allegro.cz/produkt/napajeci-zdroj-ledmax-75w-15a-5v-71bc9f56-62d9-4d03-9451-066455f0ef41?offerId=15003230425) [cit. 2026-04-07].

[10] MARLEY, S. ESP32-INMP441-Matrix-VU. Online. In: GitHub. 03. 02. 2021.

Dostupné z: https://github.com/s-marley/ESP32-INMP441-Matrix-VU. [cit. 2026-

04-07].

[11] MSALAMON_PL. Digitální LED pásek 5 V WS2812B 5050 5 m 300 IP20. Online.

In: Allegro.cz. Dostupné z: https://allegro.cz/nabidka/digitalni-led-pasek-5-v-

ws2812b-5050-5-m-300-ip20-18336710545. (https://www.google.com/search) [cit. 2026-04-07].

[12] Network Time Protocol [heslo]. Online. In: Wikipedie: Otevřená encyklopedie.
19. 04. 2024. Dostupné z: https://cs.wikipedia.org/wiki/Network_Time_Protocol.

[cit. 2026-04-07].

[13] SANTOS, Sara. ESP32 Useful Wi-Fi Library Functions (Arduino IDE). Online. In:

Random Nerd Tutorials. Dostupné z: https://randomnerdtutorials.com/esp32-

useful-wi-fi-functions-arduino/. (https://randomnerdtutorials.com/esp32-useful-wi-fi-functions-arduino/) [cit. 2026-04-07].

[14] STLXY. MH-ET LIVE Omnidirectional Microphone Module I2S Interface INMP441

MEMS. Online. In: AliExpress. Dostupné z:

https://www.aliexpress.com/item/1005009253417855.html. (https://www.google.com/search?q=https://www.aliexpress.com/item/1005009253417855.html) [cit. 2026-04-07].

## 8.2 Dokumentace a datasheety

[15] AOSONG. Temperature and humidity module DHT11 Product Manual. Online,

datasheet. Dostupné z: https://www.laskakit.cz/user/related_files/dht11.pdf. [cit.

2026-04-07].

[16] AZ-DELIVERY. DS3231 RTC Real Time Clock. Online, datasheet. Dostupné z:

https://m.media-amazon.com/images/I/C1i+9NOzn8S.pdf. [cit. 2026-04-07].

[17] ESPRESSIF SYSTEMS. ESP32 Series Datasheet. Online, datasheet. 2025.

Dostupné z: https://documentation.espressif.com/esp32_datasheet_en.pdf. [cit.

2026-04-07].

[18] ESPRESSIF SYSTEMS. ESP32-WROOM-32 Datasheet. Online, datasheet.

Dostupné z: https://www.laskakit.cz/user/related_files/esp32-wroom-

32_datasheet_en.pdf. (https://www.laskakit.cz/user/related_files/esp32-wroom-32_datasheet_en.pdf) [cit. 2026-04-07].

[19] ETC1. INMP441 Datasheet. Online, datasheet. Dostupné z:

https://pdf1.alldatasheet.com/datasheet-

pdf/view/1244625/ETC1/INMP441.html. (https://pdf1.alldatasheet.com/datasheet-pdf/view/1244625/ETC1/INMP441.html) [cit. 2026-04-07].

[20] INVENSENSE. INMP441: Omnidirectional Microphone with Bottom Port and I²S

Output Interface. Online, datasheet. 2014. Dostupné z:

https://www.laskakit.cz/user/related_files/inmp441.pdf. [cit. 2026-04-07].

[21] WORLDSEMI. WS2812B Datasheet. Online, datasheet. Dostupné z:

https://pdf1.alldatasheet.com/datasheet-

pdf/view/1179113/WORLDSEMI/WS2812B.html. (https://pdf1.alldatasheet.com/datasheet-pdf/view/1179113/WORLDSEMI/WS2812B.html) [cit. 2026-04-07].

## 8.3 Referenční videa

[22] HISTORY OF SIMPLE THINGS. RGB vs. CMYK: What’s the Difference? [video].

Online. In: YouTube. 23. 09. 2025. Dostupné z:

https://www.youtube.com/watch?v=NrISnJ4iwNg. [cit. 2026-04-07].

[23] MARLEY, Scott. 3D-printable ESP32 powered VU display with the INMP441

digital microphone and a WS2812B matrix [video]. Online. In: YouTube. 03. 02.

2021. Dostupné z: https://www.youtube.com/watch?v=9PEjvFkdpIE. [cit. 2026-

04-07].

[24] SCOTT SNEED. FastLED Basics [playlist videí]. Online. In: YouTube. 10. 12. 2020.

Dostupné z:

https://www.youtube.com/playlist?list=PLgXkGn3BBAGi5dTOCuEwrLuFtfz0kGFTC.

[cit. 2026-04-07].

## 8.4 Knihovny

[25] KRIEGSMAN, Mark a Daniel GARCIA. FastLED. Online. In: GitHub. 20. 09. 2025.

Dostupné z: https://github.com/FastLED/FastLED. [cit. 2026-04-07].

[26] MARGOLIS, Michael. Time Library. Online, verze 1.6.1. In: Arduino Docs. 21.
06. 2021. Dostupné z: https://docs.arduino.cc/libraries/time/. [cit. 2026-04-07].
[27] BLANCHON, Benoit. ArduinoJson. Online, verze 7.4.2. In: ArduinoJson.org.

Dostupné z: https://arduinojson.org/. [cit. 2026-04-07].

[28] ADAFRUIT INDUSTRIES. DHT-sensor-library. Online, verze 1.4.7. In: GitHub. 03.
03. 2024. Dostupné z: https://github.com/adafruit/DHT-sensor-library. [cit. 2026-

04-07].

[29] ADAFRUIT. RTClib. Online. In: GitHub. 09. 04. 2024. Dostupné z:

https://github.com/adafruit/RTClib. [cit. 2026-04-07].

[30] CONDES, Enrique. arduinoFFT. Online. In: GitHub. 21. 11. 2024. Dostupné z:

https://github.com/kosme/arduinoFFT. [cit. 2026-04-07].

[31] ESPRESSIF SYSTEMS. Inter-IC Sound (I2S) API Reference. Online, verze 4.4.7. In:

ESP-IDF Programming Guide. 03. 11. 2021. Dostupné z:

https://docs.espressif.com/projects/esp-idf/en/v4.4.7/esp32/api-

reference/peripherals/i2s.html. (https://docs.espressif.com/projects/esp-idf/en/v4.4.7/esp32/api-reference/peripherals/i2s.html) [cit. 2026-04-07].

[32] HERTEL, Matthias. OneButton. Online. In: GitHub. 20. 02. 2026. Dostupné z:

https://github.com/mathertel/OneButton. [cit. 2026-04-07].

[33] ARDUINO. WiFi Library Reference. Online. In: Arduino Docs. 22. 08. 2018.

Dostupné z: https://docs.arduino.cc/libraries/wifi/. [cit. 2026-04-07].

## 8.5 Softwarové nástroje

[34] AUTODESK. Fusion 360. Online, CAD software. Dostupné z:

https://www.fusion360.cz/. [cit. 2026-04-07].

[35] BAMBU LAB. Bambu Studio. Online, slicer software. Dostupné z:

https://bambulab.com/en-eu/download/studio. [cit. 2026-04-07].

[36] CANVA. Canva. Online, grafický nástroj. Dostupné z: https://www.canva.com/.

[cit. 2026-04-07].

[37] DIAGRAMS.NET. draw.io. Online, nástroj pro tvorbu schémat. Dostupné z:

https://www.drawio.com/. [cit. 2026-04-07].

[38] KICAD. KiCad EDA. Online, software pro návrh plošných spojů. Dostupné z:

https://www.kicad.org/. [cit. 2026-04-07].

[39] WOKWI. Wokwi Arduino Simulator. Online, simulátor elektroniky. Dostupné z:

https://wokwi.com/. [cit. 2026-04-07].

## 8.6 Umělá inteligence

[40] ANTHROPIC. Claude. Online, LLM model. 2026. Dostupné z: https://claude.ai/.

[cit. 2026-04-07]. Nástroj byl využit pro rozdělení zdrojového kódu do jednotlivých

podsouborů.

[41] GOOGLE. Gemini. Online, LLM model. Gemini 3. Dostupné z:

https://gemini.google.com/. [cit. 2026-04-07]. Nástroj byl využit pro kontrolu

jazykové správnosti textu a částečnou pomoc při tvorbě zdrojového kódu.

[42] OPENAI. ChatGPT. Online, LLM model. 2026. Dostupné z:

https://chatgpt.com/. [cit. 2026-04-07]. Nástroj byl využit jako asistent při psaní a

ladění zdrojového kódu.

## 8.7 Seznam obrázků

Obr. 1: WORLDSEMI. WS2812 LED. Online, obrázek. 2024. Dostupné z:

https://cdn.sanity.io/images/3y31615s/production/7957be495b92c1837fbec6cc15dd68d8a6

3763a7-1366x648.png. (https://www.google.com/search) [cit. 2026-04-07].

Obr. 2: MCAD. Additive and Subtractive Color Mixing. Online, obrázek. 2024. Dostupné z:

https://intranet.mcad.edu/sites/default/files/picture2_1.png. [cit. 2026-04-07].

Obr. 3: DRÁTEK.CZ. ESP32. Online, obrázek. 13. 01. 2021. Dostupné z:

https://dratek.cz/photos/produkty_gal/f/32/32352.jpg. (https://www.google.com/search?q=https://dratek.cz/photos/produkty_gal/f/32/32352.jpg) [cit. 2026-04-07].

Obr. 4: ALL ABOUT CIRCUITS. I2S Interface Signals. Online, obrázek. 2026. In: Introduction to

the I2S Interface. Dostupné z: https://www.allaboutcircuits.com/technical-

articles/introduction-to-the-i2s-interface/. (https://www.allaboutcircuits.com/technical-articles/introduction-to-the-i2s-interface/) [cit. 2026-04-07].

Obr. 5: HIENYSCH, Dan. I2C Timing and Addressing. Online, obrázek. 20. 01. 2015. In:

Rheingold Heavy. Dostupné z: https://rheingoldheavy.com/wp-

content/uploads/2015/01/I2C_Timing_Addressing.png. (https://www.google.com/search) [cit. 2026-04-07].

Obr. 6: ŽEŽULKA, Radim. Schéma zapojení vlastního ovladače. 2026. [obrázek]. Vlastní návrh v

softwaru KiCad EDA. Vlastní archiv autora. [cit. 2026-04-07].

Obr. 7: ŽEŽULKA, Radim. Schéma zapojení RGB displeje. 2026. [obrázek]. Vlastní návrh v

softwaru KiCad EDA. Vlastní archiv autora. [cit. 2026-04-07].

Obr. 8: ŽEŽULKA, Radim. Blokové schéma. 2026. [obrázek]. Vlastní návrh v nástroji draw.io.

Vlastní archiv autora. [cit. 2026-04-07].

Obr. 9: ŽEŽULKA, Radim. Schéma zapojení LED matice. 2026. [obrázek]. Vlastní návrh v

simulátoru Wokwi. Vlastní archiv autora. [cit. 2026-04-07].

Obr. 10: ŽEŽULKA, Radim. „Cik-cak“ zapojení LED pásku. 2026. [fotografie]. Vlastní

dokumentace realizace projektu. Vlastní archiv autora. [cit. 2026-04-07].

Obr. 11: ŽEŽULKA, Radim. Zadní strana displeje bez krytu. 2026. [fotografie]. Vlastní

dokumentace realizace projektu. Vlastní archiv autora. [cit. 2026-04-07].

Obr. 12: ŽEŽULKA, Radim. Logo menu hry had. 2026. [fotografie]. Vlastní dokumentace

realizace projektu. Vlastní archiv autora. [cit. 2026-04-07].

Obr. 13: ŽEŽULKA, Radim. Ovladač. 2026. [fotografie]. Vlastní dokumentace realizace

projektu. Vlastní archiv autora. [cit. 2026-04-07].

Obr. 14: ŽEŽULKA, Radim. Senzory v krabičce. 2026. [fotografie]. Vlastní dokumentace

realizace projektu. Vlastní archiv autora. [cit. 2026-04-07].

Obr. 15: ŽEŽULKA, Radim. Napájecí zdroj. 2026. [fotografie]. Vlastní dokumentace realizace

projektu. Vlastní archiv autora. [cit. 2026-04-07].

Obr. 16: ŽEŽULKA, Radim. Vnitřní zapojení ovladače. 2026. [fotografie]. Vlastní dokumentace

realizace projektu. Vlastní archiv autora. [cit. 2026-04-07].

Obr. 17: ŽEŽULKA, Radim. Vnitřní zapojení displeje. 2026. [fotografie]. Vlastní dokumentace

realizace projektu. Vlastní archiv autora. [cit. 2026-04-07].

Obr. 18: ALLEGRO.CZ. Digitální LED pásek 5 V WS2812B. Online, obrázek. 2026. In: Allegro.

Dostupné z:

https://a.allegroimg.com/s720/11d547/868c20eb461598d8c892817572e5/Digitalni-LED-

pasek-5-V-WS2812B-5050-5-m-300-IP20. (https://a.allegroimg.com/s720/11d547/868c20eb461598d8c892817572e5/Digitalni-LED-pasek-5-V-WS2812B-5050-5-m-300-IP20) [cit. 2026-04-07].

Obr. 19: GME.CZ. Modul RTC DS3231. Online, obrázek. 2026. In: GME.cz. Dostupné z:

https://img.gme.cz/detail_big/1200/800/eshop_data/eshop_data/10/772-

290/pctdetail.772-290.1.jpg. (https://img.gme.cz/detail_big/1200/800/eshop_data/eshop_data/10/772-290/pctdetail.772-290.1.jpg) [cit. 2026-04-07].

Obr. 20: LASKAKIT.CZ. Senzor teploty a vlhkosti vzduchu DHT11. Online, obrázek. 2026. In:

LaskaKit. Dostupné z:

https://cdn.myshoptet.cz/usr/www.laskakit.cz/user/shop/big/563_arduino-senzor-teploty-a-

vlhkosti-vzduchu-dht11--modul.jpg. (https://www.google.com/search) [cit. 2026-04-07].

Obr. 21: ELECTROPEAK.COM. Digitální I2S mikrofon INMP441. Online, obrázek. 2026. In:

ElectroPeak. Dostupné z:

https://electropeak.com/media/catalog/product/cache/a99a51fafac039a73087ecfaa8ccceba

/s/e/sen-17-149-3.jpg. (https://electropeak.com/media/catalog/product/cache/a99a51fafac039a73087ecfaa8ccceba/s/e/sen-17-149-3.jpg) [cit. 2026-04-07].

Obr. 22: ALLEGRO.CZ. Napájecí zdroj LEDMAX 75 W 15 A 5 V. Online, obrázek. 2026. In:

Allegro. Dostupné z:

https://a.allegroimg.com/s720/114bad/452a10994f92a07de1be7dd4bcc7/Napajeci-zdroj-

LEDMAX-75W-15A-5V. (https://a.allegroimg.com/s720/114bad/452a10994f92a07de1be7dd4bcc7/Napajeci-zdroj-LEDMAX-75W-15A-5V) [cit. 2026-04-07].

Obr. 23: ŽEŽULKA, Radim. Diagram menu. 2026. [obrázek]. Vlastní návrh v nástroji draw.io.

Vlastní archiv autora. [cit. 2026-04-07].

Obr. 24: ŽEŽULKA, Radim. Ukázka mapování souřadnic. 2026. [obrázek]. Vlastní autorský

nákres vizualizovaný modelem Google Gemini. Vlastní archiv autora. [cit. 2026-04-07].

## 9 Přílohy

## 9.1 Příloha č.1: Kompletní zdrojový kód

Vzhledem k rozsahu zdrojového kóduje kompletní výpis programu přiložen jako

samostatný dokument ve formátu PDF. Tato příloha obsahuje veškeré knihovny, definice efektů

a logiku ovládání LED matice.

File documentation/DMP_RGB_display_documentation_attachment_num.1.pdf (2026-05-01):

# Střední Průmyslová Škola Elektrotechnická Ječná


# DLOUHODOBÁ MATURITNÍ PRÁCE

# Příloha č.1

# Kompletní zdrojový kód

# RGB displej 16x16

# 2026 Radim Žežulka

## Obsah

# 1 Hlavní program a konfigurace

Zdrojové kódy a ostatní části práce v původním formátu jsou dostupné na:

https://github.com/zezulkaradim/RGB-Display-16-x-16

## 1.1 Main.ino

#include "config.h"

#include "display_utils.h" #include "buttons.h"

#include "clock_wifi.h"

#include "animations.h"

#include "snake.h"

#include "vumetr.h"

#include "drawing.h"

#include "sprites.h"

#include "audio_reactive.h"

// ===================== Globální proměnné =====================

CRGB leds[NUM_LEDS];

DHT dht(DHTPIN, DHTTYPE);
int teplota = 0, vlhkost = 0, teplota1 = 0, vlhkost1 = 0, teplota2 = 0, vlhkost2 = 0;
uint8_t pocetsekundDHT = 0;

const char* ssid = "Xiaomi 13T Pro"; const char* password = "lupen_smrdi_123"; unsigned long lastTimePrint = 0; unsigned long lastWiFiCheck = 0;
bool wifiConnecting = false;
unsigned long wifiConnectStart = 0;

const char* ntpServer = "pool.ntp.org";
const long gmtOffset_sec = 2 * 3600;
const int daylightOffset_sec = 0;
int hodina = 0, minuta = 0, hodina1 = 0, hodina2 = 0, minuta1 = 0, minuta2 = 0;
bool dvojtecka = true;
RTC_DS3231 rtc;

int mainmode = 0, nummainmode = 4;
bool setmainmode = true;
int poradianimace = 0, modeanimace = 0, nummodeanimace = 3; bool setmodeanimace = false, prvnipruchodpacmana = false;

strukturahada had[256];
bool starthada = false, setmodehad = false;
uint8_t xjablko = 0, yjablko = 0;
bool nahoru = false, dolu = false, doprava = false, doleva = false;
uint8_t delkahada = 0;
int pocetbodu = 0, tisicehad = 0, stovkyhad = 0, desitkyhad = 0, jednotkyhad = 0;
bool setyoulosthad = false, dotekzdi = false, blikyoulost = false;
unsigned long hadpredchozimillis = 0, hadmainlastmillis = 0;
int animacehada = 0;
bool prvnipruchodhada = false;

uint8_t raketaX = 0, raketaY = 0, hueraketa = 0, pozicerakety = HEIGHT; bool raketaleti = false;
uint8_t fazeexploze = 0;
unsigned long posledniexploze = 0, casFadeStart = 0, posledniRaketa = 0, posledniPohyb = 0;
bool fadeActive = false;
CRGB ledsohnastroj[NUM_LEDS];
uint8_t heat[WIDTH][HEIGHT];

uint8_t barHeights[16], peak[16], prevFFTValue[16]; bool setmodevumetr = false;

bool setmodekresleni = false;
WebServer server(80);
CRGB ledBuffer[WIDTH][HEIGHT];
bool needsShow = false, kresleniActive = false;

OneButton buttonUp(BUTTON_ARROW_UP, false, false); OneButton buttonRight(BUTTON_ARROW_RIGHT, false, false); OneButton buttonDown(BUTTON_ARROW_DOWN, false, false); OneButton buttonLeft(BUTTON_ARROW_LEFT, false, false); OneButton buttonHome(BUTTON_HOME, false, false);
OneButton buttonPlay(BUTTON_PLAY, false, false);

// ===================== Navigace menu =====================

void mainmodes() {
if (mainmode == 1 && setmainmode) {
if (!prvnipruchodpacmana) { FastLED.clear();
pacman();
FastLED.show();
prvnipruchodpacmana = true; }
EVERY_N_MILLISECONDS(200) { FastLED.clear();
pacman();

FastLED.show();
}
} else if (mainmode == 2 && setmainmode) { if (!prvnipruchodhada) {
FastLED.clear();
mainanimacehada();
FastLED.show();
prvnipruchodhada = true;
}
EVERY_N_MILLISECONDS(800) { FastLED.clear();
mainanimacehada();
FastLED.show();
}
} else if (mainmode == 3 && setmainmode) { FastLED.clear();
animacemikrofon();
FastLED.show();
} else if (mainmode == 4 && setmainmode) { FastLED.clear();
tuzka();
FastLED.show();
}
}

// ===================== Setup =====================

void setup() {
Serial.begin(115200);
Wire.begin(21, 22);

FastLED.addLeds<CHIPSET, DATA_PIN, COLOR_ORDER>(leds, NUM_LEDS); FastLED.setMaxPowerInVoltsAndMilliamps(VOLTS, AMPS); FastLED.setBrightness(BRIGHTNESS);
FastLED.clear();
delay(200);
FastLED.show();
delay(200);

pinMode(BUTTON_ARROW_RIGHT, INPUT_PULLUP); pinMode(BUTTON_ARROW_LEFT, INPUT_PULLUP); pinMode(BUTTON_ARROW_UP, INPUT_PULLUP); pinMode(BUTTON_ARROW_DOWN, INPUT_PULLUP); pinMode(BUTTON_HOME, INPUT_PULLUP); pinMode(BUTTON_PLAY, INPUT_PULLUP);

buttonUp.attachClick(clickup); buttonRight.attachClick(clickright); buttonDown.attachClick(clickdown);

buttonLeft.attachClick(clickleft); buttonPlay.attachClick(clickplay); buttonHome.attachClick(clickhome);

memset(heat, 0, sizeof(heat));

WiFi.mode(WIFI_STA);
WiFi.begin(ssid, password); wifiConnecting = true;
wifiConnectStart = millis();
lastWiFiCheck = millis();

if (!rtc.begin()) Serial.println("RTC nenalezen."); if (rtc.lostPower()) Serial.println("RTC bez casu.");

dht.begin();
randomSeed(esp_random());
setupAudio();
}

// ===================== Loop =====================

void loop() {
buttonRight.tick();
buttonLeft.tick();
buttonPlay.tick();
buttonHome.tick();
buttonDown.tick();
buttonUp.tick();

if (mainmode == 0 && setmainmode) nacticaszwifi();
else if (modeanimace == 0 && setmodeanimace) rainbowwave();
else if (modeanimace == 1 && setmodeanimace) rainbowcycle(); else if (modeanimace == 2 && setmodeanimace) rachejtle();
else if (modeanimace == 3 && setmodeanimace) Fire2D(50, 90, 120); else if (setmodehad && !setmainmode) snake();
else if (setmodevumetr && !setmainmode) vumetr();
else if (setmodekresleni && !setmainmode) kresleni();
else mainmodes();
}

## 1.2 Config.h

#pragma once

#include <FastLED.h>

#include <OneButton.h>

#include <WiFi.h>

#include "time.h"

#include "DHT.h"

#include "RTClib.h"

#include <arduinoFFT.h>

#include <driver/i2s.h>

#include "audio_reactive.h" #include <WebServer.h>

#include <ArduinoJson.h>

// --- Display ---
#define WIDTH 16

#define HEIGHT 16

#define NUM_LEDS (WIDTH * HEIGHT) #define DATA_PIN 5

#define COLOR_ORDER GRB

#define CHIPSET WS2812B

#define BRIGHTNESS 200

#define VOLTS 5

#define AMPS 14000

extern CRGB leds[NUM_LEDS];

// --- Tlačítka ---
#define BUTTON_ARROW_UP 25 #define BUTTON_ARROW_RIGHT 26 #define BUTTON_ARROW_DOWN 27 #define BUTTON_ARROW_LEFT 14 #define BUTTON_HOME 33

#define BUTTON_PLAY 13

// --- DHT11 ---
#define DHTPIN 4

#define DHTTYPE DHT11

extern DHT dht;
extern int teplota, vlhkost; extern int teplota1, vlhkost1; extern int teplota2, vlhkost2; extern uint8_t pocetsekundDHT;

// --- Wi-Fi ---
extern const char* ssid;
extern const char* password;

extern unsigned long lastTimePrint; extern unsigned long lastWiFiCheck; extern bool wifiConnecting;
extern unsigned long wifiConnectStart;

// --- Čas / RTC ---
extern const char* ntpServer;
extern const long gmtOffset_sec;
extern const int daylightOffset_sec;
extern int hodina, minuta;
extern int hodina1, hodina2, minuta1, minuta2; extern bool dvojtecka;
extern RTC_DS3231 rtc;

// --- Navigace / módy ---extern int mainmode;
extern int nummainmode;
extern bool setmainmode;
extern int poradianimace;
extern int modeanimace;
extern int nummodeanimace; extern bool setmodeanimace; extern bool prvnipruchodpacmana;

// --- Had ---
struct strukturahada {
uint8_t x;
uint8_t y;
};
extern strukturahada had[256];
extern bool starthada, setmodehad;
extern uint8_t xjablko, yjablko;
extern bool nahoru, dolu, doprava, doleva;
extern uint8_t delkahada;
extern int pocetbodu;
extern int tisicehad, stovkyhad, desitkyhad, jednotkyhad; extern bool setyoulosthad, dotekzdi, blikyoulost;
extern unsigned long hadpredchozimillis, hadmainlastmillis; extern int animacehada;
extern bool prvnipruchodhada;

// --- Rachejtle ---
extern uint8_t raketaX, raketaY, hueraketa, pozicerakety;
extern bool raketaleti;
extern uint8_t fazeexploze;
extern unsigned long posledniexploze, casFadeStart, posledniRaketa, posledniPohyb;
extern bool fadeActive;
extern CRGB ledsohnastroj[NUM_LEDS];

// --- Oheň ---
extern uint8_t heat[WIDTH][HEIGHT];

// --- VU metr ---
extern uint8_t barHeights[16]; extern uint8_t peak[16];
extern uint8_t prevFFTValue[16]; extern bool setmodevumetr;

// --- Kreslení ---
extern bool setmodekresleni;
extern WebServer server;
extern CRGB ledBuffer[WIDTH][HEIGHT]; extern bool needsShow, kresleniActive;

## 1.3 Buttons.cpp

#pragma once

#include "config.h"

#include "display_utils.h" #include "buttons.h"

#include "clock_wifi.h"

#include "animations.h"

#include "snake.h"

#include "vumetr.h"

#include "drawing.h"

#include "sprites.h"

#include "audio_reactive.h"

void clickright() {
if (mainmode < nummainmode && setmainmode) mainmode++;
if (modeanimace < nummodeanimace && setmodeanimace) modeanimace++; if (setmodehad && !starthada) {
starthada = true;
doprava = true;
}
if (setmodehad && starthada && !doleva) { dolu = false;
nahoru = false;
doprava = true;
doleva = false;
}
}

void clickleft() {

if (mainmode > 0 && setmainmode) mainmode--;
if (modeanimace > 0 && setmodeanimace) modeanimace--; if (setmodehad && !starthada) {
starthada = true;
doleva = true;
}
if (setmodehad && starthada && !doprava) { dolu = false;
nahoru = false;
doprava = false;
doleva = true;
}
}

void clickup() {
if (setmodehad && !starthada) { starthada = true;
nahoru = true;
}
if (setmodehad && starthada && !dolu) { dolu = false;
nahoru = true;
doprava = false;
doleva = false;
}
}

void clickdown() {
if (setmodehad && !starthada) { starthada = true;
dolu = true;
}
if (setmodehad && starthada && !nahoru) { dolu = true;
nahoru = false;
doprava = false;
doleva = false;
}
}

void clickplay() {
if (mainmode == 1 && setmainmode) { setmainmode = false;
setmodeanimace = true;
modeanimace = 0;
}
if (mainmode == 2 && setmainmode) { setmainmode = false;
setmodehad = true;

starthada = false;
}
if (setyoulosthad && setmodehad) { setyoulosthad = false;
starthada = false;
xjablko = 0;
yjablko = 0;
nahoru = false;
dolu = false;
doprava = false;
doleva = false;
delkahada = 0;
pocetbodu = 0;
tisicehad = 0;
stovkyhad = 0;
desitkyhad = 0;
jednotkyhad = 0;
dotekzdi = false;
blikyoulost = false;
for (int i = 0; i < 255; i++) { had[i].x = 0;
had[i].y = 0;
}
hadpredchozimillis = 0;
}
if (mainmode == 3 && setmainmode) { setmainmode = false;
setmodevumetr = true;
}
if (mainmode == 4 && setmainmode) { setmainmode = false;
setmodekresleni = true;
}
}

void clickhome() {
if (setmodeanimace) {
setmodeanimace = false;
setmainmode = true;
modeanimace = 0;
mainmode = 1;
}
if (setmodehad) {
setmodehad = false;
setmainmode = true;
mainmode = 2;
setyoulosthad = false;
starthada = false;
xjablko = 0;

yjablko = 0;
nahoru = false;
dolu = false;
doprava = false;
doleva = false;
delkahada = 0;
pocetbodu = 0;
tisicehad = 0;
stovkyhad = 0;
desitkyhad = 0;
jednotkyhad = 0;
dotekzdi = false;
blikyoulost = false;
for (int i = 0; i < 255; i++) { had[i].x = 0;
had[i].y = 0;
}
hadpredchozimillis = 0;
}
if (setmodevumetr) {
setmodevumetr = false;
setmainmode = true;
mainmode = 3;
}
if (setmodekresleni) {
setmodekresleni = false;
setmainmode = true;
mainmode = 4;
stopKresleni();
}
}

## 1.4 Buttons.h

#pragma once

#include <Arduino.h>

void clickright();
void clickleft();
void clickup();
void clickdown();
void clickplay();
void clickhome();

# 2 Zpracování zvuku

## 2.1 Audio_reactive.cpp

/*
* This code has been taken from the sound reactive fork of WLED by Andrew * Tuline, and the analog audio processing has been (mostly) removed as we * will only be using the INMP441.
*
* The FFT code runs on core 0 while everything else runs on core 1. This * means we can make our main code more complex without affecting the FFT * processing.
*/

#include <driver/i2s.h>

#include "config.h"

#include "display_utils.h" #include "buttons.h"

#include "clock_wifi.h"

#include "animations.h"

#include "snake.h"

#include "vumetr.h"

#include "drawing.h"

#include "sprites.h"

#include "audio_reactive.h" #include "arduinoFFT.h"

#define I2S_WS 19 | // aka LRCL

#define I2S_SD 23 | // aka DOUT

#define I2S_SCK 18 // aka BCLK #define MIN_SHOW_DELAY 15

const i2s_port_t I2S_PORT = I2S_NUM_0; const int BLOCK_SIZE = 64;

const int SAMPLE_RATE = 10240;

TaskHandle_t FFT_Task;

int squelch = 0; | // Squelch, cuts out low level sounds
int gain = 30; | // Gain, boosts input level*/
uint16_t micData; | // Analog input for FFT
uint16_t micDataSm; // Smoothed mic data, as it's a bit twitchy

const uint16_t samples = 512; // This value MUST ALWAYS be a power of 2 unsigned int sampling_period_us;
unsigned long microseconds;

double FFT_MajorPeak = 0;
double FFT_Magnitude = 0;
uint16_t mAvg = 0;

// These are the input and output vectors. Input vectors receive computed results from FFT.
double vReal[samples];
double vImag[samples];
double fftBin[samples];

// Try and normalize fftBin values to a max of 4096, so that 4096/16 = 256. // Oh, and bins 0,1,2 are no good, so we'll zero them out.
double fftCalc[16];
int fftResult[16]; | // Our calculated result table, which we feed to the
animations.
double fftResultMax[16]; // A table used for testing to determine how our post-processing is working.

// Table of linearNoise results to be multiplied by squelch in order to reduce squelch across fftResult bins.
int linearNoise[16] = { 34, 28, 26, 25, 20, 12, 9, 6, 4, 4, 3, 2, 2, 2, 2, 2 };

// Table of multiplication factors so that we can even out the frequency response.
double fftResultPink[16] = { 1.70, 1.71, 1.73, 1.78, 1.68, 1.56, 1.55, 1.63, 1.79, 1.62, 1.80, 2.06, 2.47, 3.35, 6.83, 9.55 };

// Create FFT object
ArduinoFFT<double> FFT(vReal, vImag, samples, (double)SAMPLE_RATE);

double fftAdd(int from, int to) {
int i = from;
double result = 0;
while (i <= to) {
result += fftBin[i++];
}
return result;
}

// FFT main code
void FFTcode(void* parameter) {

for (;;) {
delay(1); // DO NOT DELETE THIS LINE! It is needed to give the IDLE(0) task enough time and to keep the watchdog happy.
// taskYIELD(), yield(), vTaskDelay() and esp_task_wdt_feed() didn't seem to work.

microseconds = micros();

for (int i = 0; i < samples; i++) {
int32_t digitalSample = 0;
size_t bytes_read = 0;
esp_err_t result = i2s_read(I2S_PORT, &digitalSample, sizeof(digitalSample), &bytes_read, /*portMAX_DELAY*/ 10);
//int bytes_read = i2s_pop_sample(I2S_PORT, (char *)&digitalSample, portMAX_DELAY); // no timeout
if (bytes_read > 0) micData = abs(digitalSample >> 16);

vReal[i] = micData; // Store Mic Data in an array vImag[i] = 0;
microseconds += sampling_period_us;
}

FFT.windowing(FFT_WIN_TYP_HAMMING, FFT_FORWARD); // Weigh data
FFT.compute(FFT_FORWARD); | // Compute FFT
FFT.complexToMagnitude(); | // Compute magnitudes

//
// vReal[3 .. 255] contain useful data, each a 20Hz interval (60Hz -5120Hz).
// There could be interesting data at bins 0 to 2, but there are too many artifacts.
//
FFT.majorPeak(&FFT_MajorPeak, &FFT_Magnitude); // let the effects know which freq was most dominant

for (int i = 0; i < samples; i++) { // Values for bins 0 and 1 are WAY too large. Might as well start at 3.
double t = 0.0;
t = abs(vReal[i]);
t = t / 16.0; // Reduce magnitude. Want end result to be linear and ~4096 max.
fftBin[i] = t;
} // for()

/* This FFT post processing is a DIY endeavour. What we really need is someone with sound engineering expertise to do a great job here AND most importantly, that the animations look GREAT as a result.
*
* Andrew's updated mapping of 256 bins down to the 16 result bins with Sample Freq = 10240, samples = 512 and some overlap.
* Based on testing, the lowest/Start frequency is 60 Hz (with bin 3) and a highest/End frequency of 5120 Hz in bin 255.

* Now, Take the 60Hz and multiply by 1.320367784 to get the next frequency and so on until the end. Then detetermine the bins.
* End frequency = Start frequency * multiplier ^ 16
* Multiplier = (End frequency/ Start frequency) ^ 1/16
* Multiplier = 1.320367784
*/

// Range
fftCalc[0] = (fftAdd(3, 4)) / 2; | // 60 - 100
fftCalc[1] = (fftAdd(4, 5)) / 2; | // 80 - 120
fftCalc[2] = (fftAdd(5, 7)) / 3; | // 100 - 160
fftCalc[3] = (fftAdd(7, 9)) / 3; | // 140 - 200
fftCalc[4] = (fftAdd(9, 12)) / 4; | // 180 - 260
fftCalc[5] = (fftAdd(12, 16)) / 5; | // 240 - 340
fftCalc[6] = (fftAdd(16, 21)) / 6; | // 320 - 440
fftCalc[7] = (fftAdd(21, 28)) / 8; | // 420 - 600
fftCalc[8] = (fftAdd(29, 37)) / 10; | // 580 - 760
fftCalc[9] = (fftAdd(37, 48)) / 12; | // 740 - 980
fftCalc[10] = (fftAdd(48, 64)) / 17; | // 960 - 1300
fftCalc[11] = (fftAdd(64, 84)) / 21; | // 1280 - 1700
fftCalc[12] = (fftAdd(84, 111)) / 28; | // 1680 - 2240
fftCalc[13] = (fftAdd(111, 147)) / 37; // 2220 - 2960 fftCalc[14] = (fftAdd(147, 194)) / 48; // 2940 - 3900 fftCalc[15] = (fftAdd(194, 255)) / 62; // 3880 - 5120

// Noise supression of fftCalc bins using squelch adjustment for different input types.
for (int i = 0; i < 16; i++) {
fftCalc[i] = fftCalc[i] - (float)squelch * (float)linearNoise[i] / 4.0 <= 0 ? 0 : fftCalc[i];
}

// Adjustment for frequency curves.
for (int i = 0; i < 16; i++) {
fftCalc[i] = fftCalc[i] * fftResultPink[i];
}

// Manual linear adjustment of gain using gain adjustment for different input types.
for (int i = 0; i < 16; i++) {
fftCalc[i] = fftCalc[i] * gain / 40 + fftCalc[i] / 16.0;
}

// Now, let's dump it all into fftResult. Need to do this, otherwise other routines might grab fftResult values prematurely.
for (int i = 0; i < 16; i++) {
fftResult[i] = constrain((int)fftCalc[i], 0, 254);
}

} // for(;;)
} // FFTcode()

void setupAudio() {

// Attempt to configure INMP441 Microphone
esp_err_t err;
const i2s_config_t i2s_config = {
.mode = i2s_mode_t(I2S_MODE_MASTER | I2S_MODE_RX), // Receive, not
transfer
.sample_rate = SAMPLE_RATE * 2, | // 10240 * 2 (20480)
Hz
.bits_per_sample = I2S_BITS_PER_SAMPLE_32BIT, | // could only get it
to work with 32bits
.channel_format = I2S_CHANNEL_FMT_ONLY_LEFT, | // LEFT when pin is
tied to ground.
.communication_format = i2s_comm_format_t(I2S_COMM_FORMAT_I2S | I2S_COMM_FORMAT_I2S_MSB),
.intr_alloc_flags = ESP_INTR_FLAG_LEVEL1, // Interrupt level 1
.dma_buf_count = 8, | // number of buffers
.dma_buf_len = BLOCK_SIZE | // samples per buffer
};
const i2s_pin_config_t pin_config = {
.bck_io_num = I2S_SCK, // BCLK aka SCK
.ws_io_num = I2S_WS, | // LRCL aka WS
.data_out_num = -1, | // not used (only for speakers)
.data_in_num = I2S_SD | // DOUT aka SD
};

// Configuring the I2S driver and pins.
// This function must be called before any I2S driver read/write operations. err = i2s_driver_install(I2S_PORT, &i2s_config, 0, NULL);
if (err != ESP_OK) {
Serial.printf("Failed installing driver: %d\n", err);
while (true)
;
}
err = i2s_set_pin(I2S_PORT, &pin_config);
if (err != ESP_OK) {
Serial.printf("Failed setting pin: %d\n", err); while (true)
;
}

// Test to see if we have a digital microphone installed or not. float mean = 0.0;

int32_t samples[BLOCK_SIZE];
size_t num_bytes_read = 0;

esp_err_t result = i2s_read(I2S_PORT, &samples, BLOCK_SIZE, &num_bytes_read, portMAX_DELAY);

/*int num_bytes_read = i2s_read_bytes(I2S_PORT,
(char *)samples,
BLOCK_SIZE, // the doc says bytes, but its elements.
portMAX_DELAY); // no timeout*/

int samples_read = num_bytes_read / 8;
if (samples_read > 0) {
for (int i = 0; i < samples_read; ++i) { mean += samples[i];
}
mean = mean / BLOCK_SIZE / 16384;
if (mean != 0.0) {
} else {
Serial.println("Digital microphone is NOT present."); }
}

sampling_period_us = round(1000000 * (1.0 / SAMPLE_RATE));

// Define the FFT Task and lock it to core 0 xTaskCreatePinnedToCore(
FFTcode, | // Function to implement the task
"FFT", | // Name of the task
10000, | // Stack size in words
NULL, | // Task input parameter
1, | // Priority of the task
&FFT_Task, // Task handle
0); | // Core where the task should run
} //setupAudio()

## 2.2 Auduio_reactive.h

#pragma once

#include <Arduino.h>

extern int fftResult[16];
extern int gain;
extern int squelch;

void setupAudio();
void FFTcode(void* parameter); double fftAdd(int from, int to);

## 2.3 Vumetr.cpp

#pragma once

#include "config.h"

#include "display_utils.h" #include "buttons.h"

#include "clock_wifi.h"

#include "animations.h"

#include "snake.h"

#include "vumetr.h"

#include "drawing.h"

#include "sprites.h"

#include "audio_reactive.h" // Kvůli funkci XY()

void drawRainbowBar(uint8_t band, uint8_t height) {
for (uint8_t y = 0; y <= height; y++) {
leds[XY(band, (HEIGHT - 1) - y)] = CHSV(map(band, 0, 15, 0, 255), 255, 255);
}
}

void drawWhitePeak(uint8_t band) {
leds[XY(band, (HEIGHT - 1) - peak[band])] = CRGB::White; }

void decayPeaks() {
static uint32_t lastDecay = 0;
if (millis() - lastDecay > 60) { lastDecay = millis();
for (uint8_t i = 0; i < 16; i++) { if (peak[i] > 0) peak[i]--;
}
}
}

void vumetr() {
FastLED.clear();
for (uint8_t band = 0; band < 16; band++) {
uint8_t fftVal = ((prevFFTValue[band] * 3) + fftResult[band]) / 4; prevFFTValue[band] = fftVal;
uint8_t height = map(fftVal, 0, 255, 0, HEIGHT - 1); barHeights[band] = height;

if (height > peak[band]) peak[band] = height;

drawRainbowBar(band, height); drawWhitePeak(band);
}
decayPeaks();
FastLED.show();
}

## 2.4 Vumetr.h

#pragma once

#include <Arduino.h>

void drawRainbowBar(uint8_t band, uint8_t height); void drawWhitePeak(uint8_t band);
void decayPeaks();
void vumetr();

# 3 Hry a animace

## 3.1 Snake.cpp

#pragma once

#include "config.h"

#include "display_utils.h" #include "buttons.h"

#include "clock_wifi.h"

#include "animations.h"

#include "snake.h"

#include "vumetr.h"

#include "drawing.h"

#include "sprites.h"

#include "audio_reactive.h" void youlosthad() {

starthada = false;
setyoulosthad = true;
unsigned long hadmillisted = millis();
if (hadmillisted - hadpredchozimillis >= 400) { hadpredchozimillis = hadmillisted; blikyoulost = !blikyoulost;
}

FastLED.clear();
if (blikyoulost) {
// YOU LOST text pixel-art
int x = 0;
for (int i = 0; i <= 9; i++)
if (i < 2 || i > 4) leds[XY(x, i)] = CRGB(255, 0, 0);
x = 1;
for (int i = 0; i <= 9; i++)
if ((i > 0 && i < 4) || i > 8) leds[XY(x, i)] = CRGB(255, 0, 0); x = 2;
for (int i = 0; i <= 9; i++)
if (i < 2 || i > 8) leds[XY(x, i)] = CRGB(255, 0, 0);
x = 4;
for (int i = 0; i <= 9; i++)
if (i < 4 || i > 4) leds[XY(x, i)] = CRGB(255, 0, 0); x = 5;
leds[XY(x, 0)] = CRGB(255, 0, 0);
leds[XY(x, 3)] = CRGB(255, 0, 0);
leds[XY(x, 5)] = CRGB(255, 0, 0); leds[XY(x, 9)] = CRGB(255, 0, 0);
x = 6;
for (int i = 0; i <= 9; i++)
if (i < 4 || i > 4) leds[XY(x, i)] = CRGB(255, 0, 0);

x = 8;
for (int i = 0; i <= 7; i++)
if (i < 4 || i > 4) leds[XY(x, i)] = CRGB(255, 0, 0); leds[XY(x, 9)] = CRGB(255, 0, 0);
x = 9;
leds[XY(x, 9)] = CRGB(255, 0, 0);
leds[XY(x, 7)] = CRGB(255, 0, 0); leds[XY(x, 5)] = CRGB(255, 0, 0); leds[XY(x, 3)] = CRGB(255, 0, 0);
x = 10;
for (int i = 0; i <= 9; i++)
if (i < 4 || i > 6) leds[XY(x, i)] = CRGB(255, 0, 0); leds[XY(x, 5)] = CRGB(255, 0, 0);
x = 12;
leds[XY(x, 5)] = CRGB(255, 0, 0);
x = 13;
for (int i = 5; i <= 9; i++) leds[XY(x, i)] = CRGB(255, 0, 0); x = 14;
leds[XY(x, 5)] = CRGB(255, 0, 0);
FastLED.show();
blikyoulost = true;
} else {
for (int i = 0; i <= 159; i++) leds[i] = CRGB::Black; }

tisicehad = pocetbodu / 1000;
stovkyhad = (pocetbodu / 100) % 10; desitkyhad = (pocetbodu / 10) % 10; jednotkyhad = pocetbodu % 10;
vykreslicislo(0, 15, tisicehad, 255, 255, 255); vykreslicislo(4, 15, stovkyhad, 255, 255, 255); vykreslicislo(8, 15, desitkyhad, 255, 255, 255); vykreslicislo(12, 15, jednotkyhad, 255, 255, 255); FastLED.show();
}

void generujjablko() {
bool chyba;
do {
chyba = false;
xjablko = random(1, 15);
yjablko = random(1, 15);
for (int i = 0; i <= delkahada; i++)
if (xjablko == had[i].x && yjablko == had[i].y) { chyba = true;
break;
}
} while (chyba);
}

void haddoprava() {
if (had[0].x == xjablko && had[0].y == yjablko) { delkahada++;
pocetbodu++;
for (int i = delkahada; i > 0; i--) {
had[i].x = had[i - 1].x;
had[i].y = had[i - 1].y;
}
had[0].x++;
generujjablko();
return;
}
for (int i = 0; i <= delkahada; i++)
if (had[0].x + 1 == had[i].x && had[0].y == had[i].y) { youlosthad();
return;
}
if (had[0].x + 1 > 15) {
if (dotekzdi) youlosthad(); else dotekzdi = true;
return;
}
dotekzdi = false;
for (int i = delkahada; i > 0; i--) { had[i].x = had[i - 1].x;
had[i].y = had[i - 1].y;
}
had[0].x++;
}

void haddoleva() {
if (had[0].x == xjablko && had[0].y == yjablko) { delkahada++;
pocetbodu++;
generujjablko();
for (int i = delkahada; i > 0; i--) { had[i].x = had[i - 1].x;
had[i].y = had[i - 1].y;
}
had[0].x--;
return;
}
for (int i = 0; i <= delkahada; i++)
if (had[0].x - 1 == had[i].x && had[0].y == had[i].y) { youlosthad();
return;
}
if (had[0].x - 1 < 0) {

if (dotekzdi) youlosthad(); else dotekzdi = true;
return;
}
dotekzdi = false;
for (int i = delkahada; i > 0; i--) { had[i].x = had[i - 1].x;
had[i].y = had[i - 1].y;
}
had[0].x--;
}

void hadnahoru() {
if (had[0].x == xjablko && had[0].y == yjablko) { delkahada++;
pocetbodu++;
generujjablko();
for (int i = delkahada; i > 0; i--) { had[i].x = had[i - 1].x;
had[i].y = had[i - 1].y;
}
had[0].y--;
return;
}
for (int i = 0; i <= delkahada; i++)
if (had[0].x == had[i].x && had[0].y - 1 == had[i].y) { youlosthad();
return;
}
if (had[0].y - 1 < 0) {
if (dotekzdi) youlosthad(); else dotekzdi = true;
return;
}
dotekzdi = false;
for (int i = delkahada; i > 0; i--) { had[i].x = had[i - 1].x;
had[i].y = had[i - 1].y;
}
had[0].y--;
}

void haddolu() {
if (had[0].x == xjablko && had[0].y == yjablko) { delkahada++;
pocetbodu++;
generujjablko();
for (int i = delkahada; i > 0; i--) { had[i].x = had[i - 1].x;

had[i].y = had[i - 1].y;
}
had[0].y++;
return;
}
for (int i = 0; i <= delkahada; i++)
if (had[0].x == had[i].x && had[0].y + 1 == had[i].y) { youlosthad();
return;
}
if (had[0].y + 1 > 15) {
if (dotekzdi) youlosthad(); else dotekzdi = true;
return;
}
dotekzdi = false;
for (int i = delkahada; i > 0; i--) { had[i].x = had[i - 1].x;
had[i].y = had[i - 1].y;
}
had[0].y++;
}

void snake() {
if (setyoulosthad) {
youlosthad();
return;
}

if (!starthada) {
FastLED.clear();
while (xjablko == had[0].x && yjablko == had[0].y) { xjablko = random(1, 15);
yjablko = random(1, 15);
had[0].x = random(3, 13);
had[0].y = random(3, 13);
}
leds[XY(xjablko, yjablko)] = CRGB(255, 0, 0); leds[XY(had[0].x, had[0].y)] = CRGB(0, 255, 0); FastLED.show();
}

unsigned long now = millis();
if (now - hadmainlastmillis < (unsigned long)(500 - (5 * pocetbodu))) return;
hadmainlastmillis = now;

if (starthada) {
if (doprava) haddoprava();

if (doleva) haddoleva();
if (dolu) haddolu();
if (nahoru) hadnahoru();
FastLED.clear();
leds[XY(xjablko, yjablko)] = CRGB(255, 0, 0);
for (int i = 0; i <= delkahada; i++)
leds[XY(had[i].x, had[i].y)] = (i % 2 == 0) ? CRGB(0, 125, 0) : CRGB(0, 255, 0);
FastLED.show();
}
}

## 3.2 Snake.h

#pragma once

#include <Arduino.h>

void youlosthad();
void generujjablko();
void haddoprava();
void haddoleva();
void hadnahoru();
void haddolu();
void snake();

## 3.3 Animations.cpp

#pragma once

#include "config.h"

#include "display_utils.h" #include "buttons.h"

#include "clock_wifi.h"

#include "animations.h"

#include "snake.h"

#include "vumetr.h"

#include "drawing.h"

#include "sprites.h"

#include "audio_reactive.h"

void rainbowwave() {
FastLED.clear();
static uint16_t t = 0;
EVERY_N_MILLISECONDS(5) {
t++;
for (uint8_t y = 0; y < HEIGHT; y++)
for (uint8_t x = 0; x < WIDTH; x++)
leds[XY(x, y)] = CHSV((x * 6 + y * 6 + t) % 255, 255, 255); FastLED.show();
}

}

void rainbowcycle() {
FastLED.clear();
static uint16_t t = 0;
EVERY_N_MILLISECONDS(5) {
t++;
float cx = (WIDTH - 1) / 2.0, cy = (HEIGHT - 1) / 2.0; for (uint8_t y = 0; y < HEIGHT; y++) {
for (uint8_t x = 0; x < WIDTH; x++) {
float dx = x - cx, dy = y - cy;
uint8_t hue = (uint8_t)(atan2(dy, dx) * 40 + sqrt(dx * dx + dy * dy) * 15 + t);
leds[XY(x, y)] = CHSV(hue, 255, 255);
}
}
FastLED.show();
}
}

// --- Rachejtle ---

void exploze1() {
leds[XY(raketaX, raketaY)] = CHSV(hueraketa, 255, 255); leds[XY(raketaX + 1, raketaY)] = CHSV(hueraketa, 255, 255); leds[XY(raketaX + 1, raketaY + 1)] = CHSV(hueraketa, 255, 255); leds[XY(raketaX, raketaY + 1)] = CHSV(hueraketa, 255, 255); leds[XY(raketaX - 1, raketaY + 1)] = CHSV(hueraketa, 255, 255); leds[XY(raketaX - 1, raketaY)] = CHSV(hueraketa, 255, 255); leds[XY(raketaX - 1, raketaY - 1)] = CHSV(hueraketa, 255, 255); leds[XY(raketaX, raketaY - 1)] = CHSV(hueraketa, 255, 255); leds[XY(raketaX + 1, raketaY - 1)] = CHSV(hueraketa, 255, 255); }

void exploze2() {
exploze1();
leds[XY(raketaX + 2, raketaY)] = CHSV(hueraketa, 255, 255); leds[XY(raketaX + 3, raketaY)] = CHSV(hueraketa, 255, 255); leds[XY(raketaX, raketaY + 2)] = CHSV(hueraketa, 255, 255); leds[XY(raketaX, raketaY + 3)] = CHSV(hueraketa, 255, 255); leds[XY(raketaX - 2, raketaY)] = CHSV(hueraketa, 255, 255); leds[XY(raketaX - 3, raketaY)] = CHSV(hueraketa, 255, 255); leds[XY(raketaX, raketaY - 2)] = CHSV(hueraketa, 255, 255); leds[XY(raketaX, raketaY - 3)] = CHSV(hueraketa, 255, 255); leds[XY(raketaX + 2, raketaY + 1)] = CHSV(hueraketa, 255, 255); leds[XY(raketaX + 1, raketaY + 2)] = CHSV(hueraketa, 255, 255); leds[XY(raketaX - 1, raketaY + 2)] = CHSV(hueraketa, 255, 255); leds[XY(raketaX - 2, raketaY + 1)] = CHSV(hueraketa, 255, 255); leds[XY(raketaX - 1, raketaY - 2)] = CHSV(hueraketa, 255, 255);

leds[XY(raketaX + 1, raketaY - 2)] = CHSV(hueraketa, 255, 255); leds[XY(raketaX + 2, raketaY - 1)] = CHSV(hueraketa, 255, 255); leds[XY(raketaX - 2, raketaY - 1)] = CHSV(hueraketa, 255, 255); }

void exploze3() {
exploze2();
leds[XY(raketaX + 3, raketaY + 1)] = CHSV(hueraketa, 255, 255); leds[XY(raketaX + 3, raketaY + 2)] = CHSV(hueraketa, 255, 255); leds[XY(raketaX + 3, raketaY - 1)] = CHSV(hueraketa, 255, 255); leds[XY(raketaX + 3, raketaY - 2)] = CHSV(hueraketa, 255, 255); leds[XY(raketaX + 2, raketaY + 3)] = CHSV(hueraketa, 255, 255); leds[XY(raketaX + 1, raketaY + 3)] = CHSV(hueraketa, 255, 255); leds[XY(raketaX - 1, raketaY + 3)] = CHSV(hueraketa, 255, 255); leds[XY(raketaX - 2, raketaY + 3)] = CHSV(hueraketa, 255, 255); leds[XY(raketaX - 3, raketaY + 2)] = CHSV(hueraketa, 255, 255); leds[XY(raketaX - 3, raketaY + 1)] = CHSV(hueraketa, 255, 255); leds[XY(raketaX - 3, raketaY - 1)] = CHSV(hueraketa, 255, 255); leds[XY(raketaX - 3, raketaY - 2)] = CHSV(hueraketa, 255, 255); leds[XY(raketaX - 2, raketaY - 3)] = CHSV(hueraketa, 255, 255); leds[XY(raketaX - 1, raketaY - 3)] = CHSV(hueraketa, 255, 255); leds[XY(raketaX + 1, raketaY - 3)] = CHSV(hueraketa, 255, 255); leds[XY(raketaX + 2, raketaY - 3)] = CHSV(hueraketa, 255, 255); leds[XY(raketaX + 2, raketaY - 2)] = CHSV(hueraketa, 255, 255); leds[XY(raketaX + 2, raketaY + 2)] = CHSV(hueraketa, 255, 255); leds[XY(raketaX - 2, raketaY + 2)] = CHSV(hueraketa, 255, 255); leds[XY(raketaX - 2, raketaY - 2)] = CHSV(hueraketa, 255, 255); }

void rachejtle() {
unsigned long now = millis();

if (!raketaleti && !fadeActive && (now - posledniRaketa >= 1500)) { raketaX = random(3, 13);
raketaY = random(3, 13);
pozicerakety = HEIGHT - 1;
hueraketa += 15;
raketaleti = true;
fazeexploze = 0;
posledniRaketa = now;
}

if (raketaleti && now - posledniPohyb > 20) { FastLED.clear();
leds[XY(raketaX, pozicerakety)] = CRGB::White; FastLED.show();
pozicerakety--;
posledniPohyb = now;
if (pozicerakety <= raketaY) {

raketaleti = false;
fazeexploze = 1;
posledniexploze = now;
}
}

if (fazeexploze >= 1 && fazeexploze <= 3 && !fadeActive) { if (now - posledniexploze >= 80) {
FastLED.clear();
if (fazeexploze == 1) exploze1();
else if (fazeexploze == 2) exploze2();
else if (fazeexploze == 3) {
exploze3();
for (int i = 0; i < NUM_LEDS; i++) ledsohnastroj[i] = leds[i]; fadeActive = true;
casFadeStart = now;
}
FastLED.show();
fazeexploze++;
posledniexploze = now;
}
}

if (fadeActive) {
unsigned long elapsed = now - casFadeStart;
if (elapsed <= 1000) {
uint8_t brightness = map(elapsed, 0, 1000, 255, 0); for (int i = 0; i < NUM_LEDS; i++) {
leds[i] = ledsohnastroj[i]; leds[i].nscale8_video(brightness);
}
FastLED.show();
} else {
fadeActive = false;
FastLED.clear();
FastLED.show();
}
}
}

// --- Oheň ---

void Fire2D(uint8_t cooling, uint8_t sparking, uint8_t speedDelay) { static unsigned long last = 0;
unsigned long now = millis();
if (now - last < speedDelay) return;
last = now;

for (uint8_t x = 0; x < WIDTH; x++)

for (uint8_t y = 0; y < HEIGHT; y++)
heat[x][y] = qsub8(heat[x][y], random8(0, (cooling * 10 / HEIGHT) + 2));

uint8_t newHeat[WIDTH][HEIGHT];
memset(newHeat, 0, sizeof(newHeat));

for (uint8_t x = 0; x < WIDTH; x++) { for (uint8_t y = 0; y < HEIGHT; y++) { uint16_t sum = heat[x][y];
uint8_t count = 1;
uint8_t yb = (y < HEIGHT - 1) ? y + 1 : y; uint8_t xl = (x == 0) ? WIDTH - 1 : x - 1; uint8_t xr = (x == WIDTH - 1) ? 0 : x + 1; sum += heat[x][yb];
count++;
sum += heat[xl][yb];
count++;
sum += heat[xr][yb];
count++;
newHeat[x][y] = sum / count;
}
}
memcpy(heat, newHeat, sizeof(heat));

for (uint8_t x = 0; x < WIDTH; x++)
if (random8() < sparking)
heat[x][HEIGHT - 1] = qadd8(heat[x][HEIGHT - 1], random8(160, 255));

for (uint8_t x = 0; x < WIDTH; x++)
for (uint8_t y = 0; y < HEIGHT; y++)
leds[XY(x, y)] = ColorFromPalette(HeatColors_p, scale8(heat[x][y], 240));

FastLED.show();
}

## 3.4 Animations.h

#pragma once

#include <Arduino.h>

void rainbowwave();
void rainbowcycle();
void exploze1();
void exploze2();
void exploze3();
void rachejtle();
void Fire2D(uint8_t cooling=55, uint8_t sparking =120, uint8_t speedDelay=50);

## 3.5 Sprites.cpp

#pragma once

#include "config.h"

#include "display_utils.h" #include "buttons.h"

#include "clock_wifi.h"

#include "animations.h"

#include "snake.h"

#include "vumetr.h"

#include "drawing.h"

#include "sprites.h"

#include "audio_reactive.h"

// ===================== HAD - animace na menu =====================

void telohada1() {
int x = 0;
for (int i = 0; i <= 15; i++)
if (i > 10 && i < 14) leds[XY(x, i)] = CRGB(0, 80, 0); x = 1;
for (int i = 0; i <= 15; i++)
if (i > 7 && i < 12) leds[XY(x, i)] = CRGB(0, 80, 0); leds[XY(1, 14)] = CRGB(0, 80, 0);
leds[XY(1, 15)] = CRGB(0, 80, 0);
x = 2;
leds[XY(x, 10)] = CRGB(0, 80, 0); leds[XY(x, 11)] = CRGB(0, 80, 0); leds[XY(x, 15)] = CRGB(0, 80, 0); x = 3;
leds[XY(x, 10)] = CRGB(0, 80, 0); leds[XY(x, 11)] = CRGB(0, 80, 0); leds[XY(x, 15)] = CRGB(0, 80, 0); x = 4;
leds[XY(x, 11)] = CRGB(0, 80, 0); leds[XY(x, 15)] = CRGB(0, 80, 0); x = 5;
leds[XY(x, 11)] = CRGB(0, 80, 0); leds[XY(x, 15)] = CRGB(0, 80, 0); x = 6;
leds[XY(x, 8)] = CRGB(0, 80, 0); leds[XY(x, 11)] = CRGB(0, 80, 0); leds[XY(x, 12)] = CRGB(0, 80, 0); leds[XY(x, 15)] = CRGB(0, 80, 0); for (x = 7; x < 13; x++) { leds[XY(x, 8)] = CRGB(0, 80, 0); leds[XY(x, 12)] = CRGB(0, 80, 0); leds[XY(x, 15)] = CRGB(0, 80, 0);

}
x = 13;
leds[XY(x, 8)] = CRGB(0, 80, 0); leds[XY(x, 9)] = CRGB(0, 80, 0); leds[XY(x, 12)] = CRGB(0, 80, 0); leds[XY(x, 13)] = CRGB(0, 80, 0); leds[XY(x, 15)] = CRGB(0, 80, 0);
x = 14;
for (int i = 0; i <= 15; i++)
if (i > 10) leds[XY(x, i)] = CRGB(0, 80, 0); leds[XY(14, 9)] = CRGB(0, 80, 0);
x = 15;
for (int i = 0; i <= 15; i++)
if ((i > 8 && i < 15) && (i != 12)) leds[XY(x, i)] = CRGB(0, 80, 0);

x = 2;
leds[XY(x, 13)] = CRGB(70, 255, 0);
x = 3;
leds[XY(x, 8)] = CRGB(70, 255, 0); leds[XY(x, 9)] = CRGB(70, 255, 0); leds[XY(x, 13)] = CRGB(70, 255, 0); leds[XY(x, 14)] = CRGB(70, 255, 0); x = 4;
leds[XY(x, 8)] = CRGB(70, 255, 0); leds[XY(x, 9)] = CRGB(70, 255, 0); leds[XY(x, 10)] = CRGB(70, 255, 0); leds[XY(x, 13)] = CRGB(70, 255, 0); leds[XY(x, 14)] = CRGB(70, 255, 0); x = 5;
leds[XY(x, 9)] = CRGB(70, 255, 0); leds[XY(x, 10)] = CRGB(70, 255, 0); leds[XY(x, 13)] = CRGB(70, 255, 0); leds[XY(x, 14)] = CRGB(70, 255, 0); x = 6;
leds[XY(x, 9)] = CRGB(70, 255, 0); leds[XY(x, 10)] = CRGB(70, 255, 0); leds[XY(x, 13)] = CRGB(70, 255, 0); leds[XY(x, 14)] = CRGB(70, 255, 0); x = 7;
leds[XY(x, 9)] = CRGB(70, 255, 0); leds[XY(x, 10)] = CRGB(70, 255, 0); leds[XY(x, 14)] = CRGB(70, 255, 0); for (x = 7; x < 12; x++) { leds[XY(x, 9)] = CRGB(70, 255, 0); leds[XY(x, 10)] = CRGB(70, 255, 0); leds[XY(x, 11)] = CRGB(70, 255, 0); leds[XY(x, 14)] = CRGB(70, 255, 0); }
x = 12;

leds[XY(x, 10)] = CRGB(70, 255, 0); leds[XY(x, 11)] = CRGB(70, 255, 0); leds[XY(x, 14)] = CRGB(70, 255, 0); x = 13;
leds[XY(x, 10)] = CRGB(70, 255, 0);

x = 1;
leds[XY(x, 12)] = CRGB(0, 255, 0); leds[XY(x, 13)] = CRGB(0, 255, 0); x = 2;
leds[XY(x, 8)] = CRGB(0, 255, 0); leds[XY(x, 9)] = CRGB(0, 255, 0); leds[XY(x, 12)] = CRGB(0, 255, 0); leds[XY(x, 14)] = CRGB(0, 255, 0); x = 3;
leds[XY(x, 12)] = CRGB(0, 255, 0); x = 4;
leds[XY(x, 12)] = CRGB(0, 255, 0); x = 5;
leds[XY(x, 8)] = CRGB(0, 255, 0); leds[XY(x, 12)] = CRGB(0, 255, 0); x = 7;
leds[XY(x, 11)] = CRGB(0, 255, 0);
leds[XY(x, 13)] = CRGB(0, 255, 0);
for (x = 7; x < 12; x++) leds[XY(x, 13)] = CRGB(70, 255, 0); x = 12;
leds[XY(x, 9)] = CRGB(0, 255, 0);
leds[XY(x, 13)] = CRGB(0, 255, 0);
x = 13;
leds[XY(x, 11)] = CRGB(0, 255, 0); leds[XY(x, 14)] = CRGB(0, 255, 0); x = 14;
leds[XY(x, 10)] = CRGB(0, 255, 0); }

void telohada2() {
int x = 0;
for (int i = 0; i <= 15; i++)
if (i > 10 && i < 14) leds[XY(x, i)] = CRGB(0, 80, 0); x = 1;
for (int i = 0; i <= 15; i++)
if (i > 7 && i < 12) leds[XY(x, i)] = CRGB(0, 80, 0); leds[XY(1, 14)] = CRGB(0, 80, 0);
leds[XY(1, 15)] = CRGB(0, 80, 0);
x = 2;
leds[XY(x, 8)] = CRGB(0, 80, 0); leds[XY(x, 10)] = CRGB(0, 80, 0); leds[XY(x, 11)] = CRGB(0, 80, 0); leds[XY(x, 15)] = CRGB(0, 80, 0);

x = 3;
leds[XY(x, 10)] = CRGB(0, 80, 0); leds[XY(x, 11)] = CRGB(0, 80, 0); leds[XY(x, 15)] = CRGB(0, 80, 0); x = 4;
leds[XY(x, 11)] = CRGB(0, 80, 0); leds[XY(x, 15)] = CRGB(0, 80, 0); x = 5;
leds[XY(x, 11)] = CRGB(0, 80, 0); leds[XY(x, 15)] = CRGB(0, 80, 0); x = 6;
leds[XY(x, 8)] = CRGB(0, 80, 0); leds[XY(x, 11)] = CRGB(0, 80, 0); leds[XY(x, 12)] = CRGB(0, 80, 0); leds[XY(x, 15)] = CRGB(0, 80, 0); for (x = 7; x < 13; x++) { leds[XY(x, 8)] = CRGB(0, 80, 0); leds[XY(x, 12)] = CRGB(0, 80, 0); leds[XY(x, 15)] = CRGB(0, 80, 0); }
x = 13;
leds[XY(x, 8)] = CRGB(0, 80, 0); leds[XY(x, 9)] = CRGB(0, 80, 0); leds[XY(x, 12)] = CRGB(0, 80, 0); leds[XY(x, 13)] = CRGB(0, 80, 0); leds[XY(x, 15)] = CRGB(0, 80, 0);
x = 14;
for (int i = 0; i <= 15; i++)
if (i > 10) leds[XY(x, i)] = CRGB(0, 80, 0); leds[XY(14, 9)] = CRGB(0, 80, 0);
x = 15;
for (int i = 0; i <= 15; i++)
if ((i > 8 && i < 15) && (i != 12)) leds[XY(x, i)] = CRGB(0, 80, 0);

x = 2;
leds[XY(x, 13)] = CRGB(70, 255, 0);
x = 3;
leds[XY(x, 8)] = CRGB(70, 255, 0); leds[XY(x, 9)] = CRGB(70, 255, 0); leds[XY(x, 13)] = CRGB(70, 255, 0); leds[XY(x, 14)] = CRGB(70, 255, 0); x = 4;
leds[XY(x, 8)] = CRGB(70, 255, 0); leds[XY(x, 9)] = CRGB(70, 255, 0); leds[XY(x, 10)] = CRGB(70, 255, 0); leds[XY(x, 13)] = CRGB(70, 255, 0); leds[XY(x, 14)] = CRGB(70, 255, 0); x = 5;
leds[XY(x, 9)] = CRGB(70, 255, 0);

leds[XY(x, 10)] = CRGB(70, 255, 0); leds[XY(x, 13)] = CRGB(70, 255, 0); leds[XY(x, 14)] = CRGB(70, 255, 0); x = 6;
leds[XY(x, 9)] = CRGB(70, 255, 0); leds[XY(x, 10)] = CRGB(70, 255, 0); leds[XY(x, 13)] = CRGB(70, 255, 0); leds[XY(x, 14)] = CRGB(70, 255, 0); x = 7;
leds[XY(x, 9)] = CRGB(70, 255, 0); leds[XY(x, 10)] = CRGB(70, 255, 0); leds[XY(x, 14)] = CRGB(70, 255, 0); for (x = 7; x < 12; x++) { leds[XY(x, 9)] = CRGB(70, 255, 0); leds[XY(x, 10)] = CRGB(70, 255, 0); leds[XY(x, 11)] = CRGB(70, 255, 0); leds[XY(x, 14)] = CRGB(70, 255, 0); }
x = 12;
leds[XY(x, 10)] = CRGB(70, 255, 0); leds[XY(x, 11)] = CRGB(70, 255, 0); leds[XY(x, 14)] = CRGB(70, 255, 0); x = 13;
leds[XY(x, 10)] = CRGB(70, 255, 0);

x = 1;
leds[XY(x, 12)] = CRGB(0, 255, 0); leds[XY(x, 13)] = CRGB(0, 255, 0); x = 2;
leds[XY(x, 9)] = CRGB(0, 255, 0); leds[XY(x, 12)] = CRGB(0, 255, 0); leds[XY(x, 14)] = CRGB(0, 255, 0); x = 3;
leds[XY(x, 12)] = CRGB(0, 255, 0); x = 4;
leds[XY(x, 12)] = CRGB(0, 255, 0); x = 5;
leds[XY(x, 8)] = CRGB(0, 255, 0); leds[XY(x, 12)] = CRGB(0, 255, 0); x = 7;
leds[XY(x, 11)] = CRGB(0, 255, 0);
leds[XY(x, 13)] = CRGB(0, 255, 0);
for (x = 7; x < 12; x++) leds[XY(x, 13)] = CRGB(70, 255, 0); x = 12;
leds[XY(x, 9)] = CRGB(0, 255, 0);
leds[XY(x, 13)] = CRGB(0, 255, 0);
x = 13;
leds[XY(x, 11)] = CRGB(0, 255, 0); leds[XY(x, 14)] = CRGB(0, 255, 0);

x = 14;
leds[XY(x, 10)] = CRGB(0, 255, 0); }

void krkhada1() {
int x = 2;
leds[XY(x, 6)] = CRGB(0, 80, 0); leds[XY(x, 7)] = CRGB(0, 80, 0); x = 3;
leds[XY(x, 4)] = CRGB(0, 80, 0); leds[XY(x, 5)] = CRGB(0, 80, 0); x = 4;
leds[XY(x, 3)] = CRGB(0, 80, 0); leds[XY(x, 4)] = CRGB(0, 80, 0); x = 5;
leds[XY(x, 3)] = CRGB(0, 80, 0); leds[XY(x, 7)] = CRGB(0, 80, 0); x = 6;
leds[XY(x, 2)] = CRGB(0, 80, 0); leds[XY(x, 6)] = CRGB(0, 80, 0); leds[XY(x, 7)] = CRGB(0, 80, 0); x = 7;
leds[XY(x, 2)] = CRGB(0, 80, 0); leds[XY(x, 5)] = CRGB(0, 80, 0); x = 3;
leds[XY(x, 7)] = CRGB(70, 255, 0); x = 7;
leds[XY(x, 3)] = CRGB(70, 255, 0); leds[XY(x, 4)] = CRGB(70, 255, 0); x = 3;
leds[XY(x, 6)] = CRGB(0, 255, 0); x = 4;
leds[XY(x, 5)] = CRGB(0, 255, 0); leds[XY(x, 6)] = CRGB(0, 255, 0); leds[XY(x, 7)] = CRGB(0, 255, 0); x = 5;
leds[XY(x, 4)] = CRGB(0, 255, 0); leds[XY(x, 5)] = CRGB(0, 255, 0); leds[XY(x, 6)] = CRGB(0, 255, 0); x = 6;
leds[XY(x, 3)] = CRGB(0, 255, 0); leds[XY(x, 4)] = CRGB(0, 255, 0); leds[XY(x, 5)] = CRGB(0, 255, 0); }

void krkhada2() {
int x = 2;
leds[XY(x, 6)] = CRGB(0, 80, 0); leds[XY(x, 7)] = CRGB(0, 80, 0);

x = 3;
leds[XY(x, 5)] = CRGB(0, 80, 0); x = 4;
leds[XY(x, 4)] = CRGB(0, 80, 0); x = 6;
leds[XY(x, 7)] = CRGB(0, 80, 0); x = 7;
leds[XY(x, 7)] = CRGB(0, 80, 0); x = 3;
leds[XY(x, 7)] = CRGB(70, 255, 0); x = 3;
leds[XY(x, 6)] = CRGB(0, 255, 0); x = 4;
leds[XY(x, 5)] = CRGB(0, 255, 0); leds[XY(x, 6)] = CRGB(0, 255, 0); leds[XY(x, 7)] = CRGB(0, 255, 0); x = 5;
leds[XY(x, 5)] = CRGB(0, 255, 0); leds[XY(x, 6)] = CRGB(0, 255, 0); leds[XY(x, 7)] = CRGB(0, 255, 0); x = 6;
leds[XY(x, 5)] = CRGB(0, 255, 0); leds[XY(x, 6)] = CRGB(0, 255, 0); }

void hlavahada1() {
int x = 8;
leds[XY(x, 1)] = CRGB(0, 80, 0); leds[XY(x, 5)] = CRGB(0, 80, 0); x = 9;
leds[XY(x, 1)] = CRGB(0, 80, 0); leds[XY(x, 6)] = CRGB(0, 80, 0); x = 10;
leds[XY(x, 1)] = CRGB(0, 80, 0); leds[XY(x, 6)] = CRGB(0, 80, 0); x = 11;
leds[XY(x, 2)] = CRGB(0, 80, 0); leds[XY(x, 4)] = CRGB(0, 80, 0); x = 12;
leds[XY(x, 3)] = CRGB(0, 80, 0); leds[XY(x, 4)] = CRGB(0, 80, 0); x = 8;
leds[XY(x, 3)] = CRGB(70, 255, 0); leds[XY(x, 4)] = CRGB(70, 255, 0); x = 9;
leds[XY(x, 2)] = CRGB(70, 255, 0); leds[XY(x, 3)] = CRGB(70, 255, 0); leds[XY(x, 4)] = CRGB(70, 255, 0); x = 10;

leds[XY(x, 2)] = CRGB(70, 255, 0); leds[XY(x, 3)] = CRGB(70, 255, 0); leds[XY(x, 4)] = CRGB(70, 255, 0); x = 11;
leds[XY(x, 3)] = CRGB(70, 255, 0); x = 9;
leds[XY(x, 5)] = CRGB(0, 255, 0);
x = 8;
leds[XY(x, 2)] = CRGB(162, 255, 196); x = 12;
leds[XY(x, 2)] = CRGB(162, 255, 196); x = 10;
leds[XY(x, 5)] = CRGB(133, 0, 0);
x = 11;
leds[XY(x, 6)] = CRGB(255, 0, 0); }

void hlavahada2() {
int x = 8;
leds[XY(x, 5)] = CRGB(0, 80, 0); x = 9;
leds[XY(x, 1)] = CRGB(0, 80, 0); leds[XY(x, 4)] = CRGB(0, 80, 0); leds[XY(x, 5)] = CRGB(0, 80, 0); leds[XY(x, 6)] = CRGB(0, 80, 0); x = 10;
leds[XY(x, 0)] = CRGB(0, 80, 0); leds[XY(x, 3)] = CRGB(0, 80, 0); leds[XY(x, 6)] = CRGB(0, 80, 0); x = 11;
leds[XY(x, 0)] = CRGB(0, 80, 0); leds[XY(x, 3)] = CRGB(0, 80, 0); leds[XY(x, 6)] = CRGB(0, 80, 0); x = 12;
leds[XY(x, 1)] = CRGB(0, 80, 0); leds[XY(x, 2)] = CRGB(0, 80, 0); x = 8;
leds[XY(x, 2)] = CRGB(70, 255, 0); leds[XY(x, 3)] = CRGB(70, 255, 0); leds[XY(x, 4)] = CRGB(70, 255, 0); x = 9;
leds[XY(x, 2)] = CRGB(70, 255, 0); leds[XY(x, 3)] = CRGB(70, 255, 0); x = 10;
leds[XY(x, 1)] = CRGB(70, 255, 0); leds[XY(x, 2)] = CRGB(70, 255, 0); x = 11;
leds[XY(x, 1)] = CRGB(70, 255, 0); x = 11;

leds[XY(x, 2)] = CRGB(0, 255, 0);
x = 8;
leds[XY(x, 1)] = CRGB(162, 255, 196); x = 12;
leds[XY(x, 0)] = CRGB(162, 255, 196); x = 10;
leds[XY(x, 4)] = CRGB(133, 0, 0); leds[XY(x, 5)] = CRGB(133, 0, 0);
x = 11;
leds[XY(x, 5)] = CRGB(255, 0, 0); x = 12;
leds[XY(x, 5)] = CRGB(255, 0, 0); x = 13;
leds[XY(x, 6)] = CRGB(255, 0, 0); }

void hlavahada3() {
int x = 5;
leds[XY(x, 3)] = CRGB(0, 80, 0); x = 6;
leds[XY(x, 3)] = CRGB(0, 80, 0); x = 7;
leds[XY(x, 3)] = CRGB(0, 80, 0); leds[XY(x, 6)] = CRGB(0, 80, 0); for (x = 8; x <= 11; x++) { leds[XY(x, 2)] = CRGB(0, 80, 0); leds[XY(x, 6)] = CRGB(0, 80, 0); }
x = 12;
leds[XY(x, 3)] = CRGB(0, 80, 0); leds[XY(x, 6)] = CRGB(0, 80, 0); x = 13;
leds[XY(x, 4)] = CRGB(0, 80, 0); leds[XY(x, 5)] = CRGB(0, 80, 0); x = 8;
leds[XY(x, 4)] = CRGB(70, 255, 0); leds[XY(x, 5)] = CRGB(70, 255, 0); x = 9;
leds[XY(x, 4)] = CRGB(70, 255, 0); leds[XY(x, 5)] = CRGB(70, 255, 0); x = 10;
leds[XY(x, 3)] = CRGB(70, 255, 0); leds[XY(x, 4)] = CRGB(70, 255, 0); leds[XY(x, 5)] = CRGB(70, 255, 0); x = 11;
leds[XY(x, 3)] = CRGB(70, 255, 0); leds[XY(x, 4)] = CRGB(70, 255, 0); leds[XY(x, 5)] = CRGB(70, 255, 0); x = 12;

leds[XY(x, 4)] = CRGB(70, 255, 0); leds[XY(x, 5)] = CRGB(70, 255, 0); x = 5;
leds[XY(x, 4)] = CRGB(0, 255, 0); x = 6;
leds[XY(x, 4)] = CRGB(0, 255, 0); x = 7;
leds[XY(x, 4)] = CRGB(0, 255, 0); leds[XY(x, 5)] = CRGB(0, 255, 0); x = 8;
leds[XY(x, 3)] = CRGB(0, 255, 0);
x = 9;
leds[XY(x, 3)] = CRGB(162, 255, 196); x = 13;
leds[XY(x, 3)] = CRGB(162, 255, 196); }

void hlavahada4() {
int x = 5;
leds[XY(x, 4)] = CRGB(0, 80, 0); x = 6;
leds[XY(x, 3)] = CRGB(0, 80, 0); x = 7;
leds[XY(x, 3)] = CRGB(0, 80, 0); for (x = 8; x <= 11; x++) { leds[XY(x, 3)] = CRGB(0, 80, 0); leds[XY(x, 7)] = CRGB(0, 80, 0); }
x = 12;
leds[XY(x, 4)] = CRGB(0, 80, 0); leds[XY(x, 7)] = CRGB(0, 80, 0); x = 13;
leds[XY(x, 5)] = CRGB(0, 80, 0); leds[XY(x, 6)] = CRGB(0, 80, 0); x = 8;
leds[XY(x, 5)] = CRGB(70, 255, 0); x = 9;
leds[XY(x, 5)] = CRGB(70, 255, 0); leds[XY(x, 6)] = CRGB(70, 255, 0); x = 10;
leds[XY(x, 4)] = CRGB(70, 255, 0); leds[XY(x, 5)] = CRGB(70, 255, 0); leds[XY(x, 6)] = CRGB(70, 255, 0); x = 11;
leds[XY(x, 4)] = CRGB(70, 255, 0); leds[XY(x, 5)] = CRGB(70, 255, 0); leds[XY(x, 6)] = CRGB(70, 255, 0); x = 12;
leds[XY(x, 5)] = CRGB(70, 255, 0);

leds[XY(x, 6)] = CRGB(70, 255, 0); x = 6;
leds[XY(x, 4)] = CRGB(0, 255, 0); x = 7;
leds[XY(x, 4)] = CRGB(0, 255, 0); leds[XY(x, 5)] = CRGB(0, 255, 0); leds[XY(x, 6)] = CRGB(0, 255, 0); x = 8;
leds[XY(x, 4)] = CRGB(0, 255, 0); leds[XY(x, 6)] = CRGB(0, 255, 0);
x = 9;
leds[XY(x, 4)] = CRGB(162, 255, 196); x = 13;
leds[XY(x, 4)] = CRGB(162, 255, 196); }

void mainanimacehada() {
for (int i = 0; i < NUM_LEDS; i++) leds[i] = CRGB(0, 15, 15); if (animacehada == 0) {
telohada2();
krkhada2();
hlavahada4();
animacehada++;
} else if (animacehada == 1) { telohada2();
krkhada2();
hlavahada3();
animacehada++;
} else if (animacehada == 2) { telohada1();
krkhada1();
hlavahada1();
animacehada++;
} else if (animacehada == 3) { telohada1();
krkhada1();
hlavahada2();
animacehada++;
} else if (animacehada == 4) { telohada1();
krkhada1();
hlavahada1();
animacehada++;
} else if (animacehada == 5) { telohada2();
krkhada2();
hlavahada3();
animacehada++;
} else if (animacehada == 6) {

telohada2();
krkhada2();
hlavahada4();
animacehada++;
}
if (animacehada >= 6) animacehada = 0;
}

// ===================== MIKROFON ikona =====================

void animacemikrofon() {
for (int i = 0; i < NUM_LEDS; i++) leds[i] = CRGB(15, 0, 15); int x = 0;
leds[XY(x, 7)] = CRGB(255, 255, 255);
x = 1;
leds[XY(x, 7)] = CRGB(255, 255, 255); leds[XY(x, 6)] = CRGB(255, 255, 255); leds[XY(x, 5)] = CRGB(255, 255, 255); leds[XY(x, 4)] = CRGB(255, 255, 255); x = 2;
leds[XY(x, 5)] = CRGB(255, 255, 255); x = 4;
leds[XY(x, 4)] = CRGB(255, 255, 255); leds[XY(x, 9)] = CRGB(255, 255, 255); leds[XY(x, 10)] = CRGB(255, 255, 255); x = 5;
leds[XY(x, 4)] = CRGB(255, 255, 255); leds[XY(x, 3)] = CRGB(255, 255, 255); leds[XY(x, 2)] = CRGB(255, 255, 255); leds[XY(x, 1)] = CRGB(255, 255, 255); leds[XY(x, 8)] = CRGB(255, 255, 255); leds[XY(x, 9)] = CRGB(255, 255, 255); x = 6;
leds[XY(x, 2)] = CRGB(255, 255, 255); leds[XY(x, 7)] = CRGB(255, 255, 255); leds[XY(x, 8)] = CRGB(255, 255, 255); x = 7;
leds[XY(x, 6)] = CRGB(255, 255, 255); leds[XY(x, 7)] = CRGB(255, 255, 255); x = 10;
leds[XY(x, 2)] = CRGB(255, 255, 255); x = 11;
leds[XY(x, 1)] = CRGB(255, 255, 255); leds[XY(x, 2)] = CRGB(255, 255, 255); leds[XY(x, 3)] = CRGB(255, 255, 255); x = 12;
leds[XY(x, 2)] = CRGB(255, 255, 255); x = 4;
leds[XY(x, 11)] = CRGB(130, 130, 130);

x = 5;
leds[XY(x, 11)] = CRGB(130, 130, 130); leds[XY(x, 10)] = CRGB(130, 130, 130); x = 6;
leds[XY(x, 11)] = CRGB(130, 130, 130); x = 7;
leds[XY(x, 10)] = CRGB(130, 130, 130);
x = 8;
for (int i = 5; i <= 9; i++) leds[XY(x, i)] = CRGB(130, 130, 130); x = 9;
leds[XY(x, 8)] = CRGB(130, 130, 130);
leds[XY(x, 7)] = CRGB(130, 130, 130);
leds[XY(x, 6)] = CRGB(130, 130, 130); leds[XY(x, 2)] = CRGB(130, 130, 130); x = 10;
leds[XY(x, 7)] = CRGB(130, 130, 130); leds[XY(x, 3)] = CRGB(130, 130, 130); leds[XY(x, 1)] = CRGB(130, 130, 130); x = 11;
leds[XY(x, 4)] = CRGB(130, 130, 130); leds[XY(x, 0)] = CRGB(130, 130, 130); x = 12;
leds[XY(x, 3)] = CRGB(130, 130, 130); leds[XY(x, 1)] = CRGB(130, 130, 130); x = 13;
leds[XY(x, 2)] = CRGB(130, 130, 130);
x = 3;
for (int i = 9; i <= 13; i++) leds[XY(x, i)] = CRGB(80, 80, 80); x = 4;
leds[XY(x, 14)] = CRGB(80, 80, 80);
leds[XY(x, 12)] = CRGB(80, 80, 80);
leds[XY(x, 8)] = CRGB(80, 80, 80); x = 5;
leds[XY(x, 15)] = CRGB(80, 80, 80); leds[XY(x, 12)] = CRGB(80, 80, 80); leds[XY(x, 7)] = CRGB(80, 80, 80); x = 6;
leds[XY(x, 15)] = CRGB(80, 80, 80); leds[XY(x, 12)] = CRGB(80, 80, 80); leds[XY(x, 10)] = CRGB(80, 80, 80); leds[XY(x, 9)] = CRGB(80, 80, 80); leds[XY(x, 6)] = CRGB(80, 80, 80); x = 7;
leds[XY(x, 15)] = CRGB(80, 80, 80); leds[XY(x, 11)] = CRGB(80, 80, 80); leds[XY(x, 9)] = CRGB(80, 80, 80); leds[XY(x, 8)] = CRGB(80, 80, 80); leds[XY(x, 5)] = CRGB(80, 80, 80); x = 8;

leds[XY(x, 14)] = CRGB(80, 80, 80);
leds[XY(x, 10)] = CRGB(80, 80, 80);
for (int i = 2; i <= 4; i++) leds[XY(x, i)] = CRGB(80, 80, 80); x = 9;
leds[XY(x, 13)] = CRGB(80, 80, 80);
leds[XY(x, 9)] = CRGB(80, 80, 80);
leds[XY(x, 5)] = CRGB(80, 80, 80); leds[XY(x, 4)] = CRGB(80, 80, 80); leds[XY(x, 3)] = CRGB(80, 80, 80); leds[XY(x, 1)] = CRGB(80, 80, 80); x = 10;
leds[XY(x, 12)] = CRGB(80, 80, 80); leds[XY(x, 8)] = CRGB(80, 80, 80); leds[XY(x, 6)] = CRGB(80, 80, 80); leds[XY(x, 5)] = CRGB(80, 80, 80); leds[XY(x, 4)] = CRGB(80, 80, 80); leds[XY(x, 0)] = CRGB(80, 80, 80); x = 11;
leds[XY(x, 11)] = CRGB(80, 80, 80); leds[XY(x, 7)] = CRGB(80, 80, 80); leds[XY(x, 6)] = CRGB(80, 80, 80); leds[XY(x, 5)] = CRGB(80, 80, 80); x = 12;
leds[XY(x, 11)] = CRGB(80, 80, 80);
leds[XY(x, 0)] = CRGB(80, 80, 80);
for (int i = 4; i <= 7; i++) leds[XY(x, i)] = CRGB(80, 80, 80); x = 13;
leds[XY(x, 11)] = CRGB(80, 80, 80);
leds[XY(x, 15)] = CRGB(80, 80, 80);
leds[XY(x, 1)] = CRGB(80, 80, 80);
leds[XY(x, 0)] = CRGB(80, 80, 80);
for (int i = 3; i <= 7; i++) leds[XY(x, i)] = CRGB(80, 80, 80); x = 14;
for (int i = 12; i <= 14; i++) leds[XY(x, i)] = CRGB(80, 80, 80); for (int i = 1; i <= 6; i++) leds[XY(x, i)] = CRGB(80, 80, 80); x = 15;
for (int i = 2; i <= 5; i++) leds[XY(x, i)] = CRGB(80, 80, 80); }

// ===================== TUŽKA ikona =====================

void tuzka() {
for (int i = 0; i < NUM_LEDS; i++) leds[i] = CRGB(0, 15, 15); int x = 4;
leds[XY(x, 8)] = CRGB(255, 180, 120);
leds[XY(x, 9)] = CRGB(255, 180, 120);
x = 5;
leds[XY(x, 9)] = CRGB(255, 180, 120); leds[XY(x, 10)] = CRGB(255, 180, 120);

x = 6;
leds[XY(x, 10)] = CRGB(255, 180, 120); leds[XY(4, 10)] = CRGB(0, 0, 0); leds[XY(12, 11)] = CRGB(0, 0, 0); leds[XY(13, 11)] = CRGB(0, 0, 0); leds[XY(4, 12)] = CRGB(0, 0, 0); leds[XY(5, 12)] = CRGB(0, 0, 0); leds[XY(6, 12)] = CRGB(0, 0, 0); leds[XY(7, 12)] = CRGB(0, 0, 0); leds[XY(10, 12)] = CRGB(0, 0, 0); leds[XY(11, 12)] = CRGB(0, 0, 0); leds[XY(14, 12)] = CRGB(0, 0, 0); leds[XY(8, 13)] = CRGB(0, 0, 0); leds[XY(9, 13)] = CRGB(0, 0, 0);
x = 4;
leds[XY(x, 7)] = CRGB(100, 100, 0); x = 5;
leds[XY(x, 7)] = CRGB(100, 100, 0); leds[XY(x, 6)] = CRGB(100, 100, 0); x = 6;
leds[XY(x, 6)] = CRGB(100, 100, 0); leds[XY(x, 5)] = CRGB(100, 100, 0); x = 7;
leds[XY(x, 10)] = CRGB(100, 100, 0); leds[XY(x, 9)] = CRGB(100, 100, 0); leds[XY(x, 5)] = CRGB(100, 100, 0); leds[XY(x, 4)] = CRGB(100, 100, 0); x = 8;
leds[XY(x, 9)] = CRGB(100, 100, 0); leds[XY(x, 8)] = CRGB(100, 100, 0); leds[XY(x, 4)] = CRGB(100, 100, 0); leds[XY(x, 3)] = CRGB(100, 100, 0); x = 9;
leds[XY(x, 8)] = CRGB(100, 100, 0); leds[XY(x, 7)] = CRGB(100, 100, 0); leds[XY(x, 3)] = CRGB(100, 100, 0); x = 10;
leds[XY(x, 6)] = CRGB(100, 100, 0); leds[XY(x, 7)] = CRGB(100, 100, 0); x = 11;
leds[XY(x, 6)] = CRGB(100, 100, 0); leds[XY(x, 5)] = CRGB(100, 100, 0); x = 5;
leds[XY(x, 8)] = CRGB(255, 255, 0); x = 6;
leds[XY(x, 7)] = CRGB(255, 255, 0); leds[XY(x, 8)] = CRGB(255, 255, 0); leds[XY(x, 9)] = CRGB(255, 255, 0); x = 7;

leds[XY(x, 6)] = CRGB(255, 255, 0); leds[XY(x, 7)] = CRGB(255, 255, 0); leds[XY(x, 8)] = CRGB(255, 255, 0); x = 8;
leds[XY(x, 5)] = CRGB(255, 255, 0); leds[XY(x, 6)] = CRGB(255, 255, 0); leds[XY(x, 7)] = CRGB(255, 255, 0); x = 9;
leds[XY(x, 4)] = CRGB(255, 255, 0); leds[XY(x, 5)] = CRGB(255, 255, 0); leds[XY(x, 6)] = CRGB(255, 255, 0); x = 10;
leds[XY(x, 4)] = CRGB(255, 255, 0); leds[XY(x, 5)] = CRGB(255, 255, 0); x = 10;
leds[XY(x, 3)] = CRGB(255, 255, 255); x = 11;
leds[XY(x, 2)] = CRGB(255, 255, 255); leds[XY(x, 3)] = CRGB(255, 255, 255); leds[XY(x, 4)] = CRGB(255, 255, 255); x = 12;
leds[XY(x, 2)] = CRGB(255, 255, 255); leds[XY(x, 3)] = CRGB(255, 255, 255); x = 9;
leds[XY(x, 2)] = CRGB(80, 80, 80); x = 10;
leds[XY(x, 1)] = CRGB(80, 80, 80); leds[XY(x, 2)] = CRGB(80, 80, 80); x = 11;
leds[XY(x, 1)] = CRGB(80, 80, 80); x = 12;
leds[XY(x, 4)] = CRGB(80, 80, 80); leds[XY(x, 5)] = CRGB(80, 80, 80); x = 13;
leds[XY(x, 3)] = CRGB(80, 80, 80); leds[XY(x, 4)] = CRGB(80, 80, 80); x = 12;
leds[XY(x, 1)] = CRGB(255, 0, 0); x = 13;
leds[XY(x, 1)] = CRGB(255, 0, 0); leds[XY(x, 2)] = CRGB(255, 0, 0); x = 11;
leds[XY(x, 0)] = CRGB(100, 0, 0); x = 12;
leds[XY(x, 0)] = CRGB(100, 0, 0); x = 14;
leds[XY(x, 2)] = CRGB(100, 0, 0); leds[XY(x, 3)] = CRGB(100, 0, 0); }

// ===================== PACMAN =====================

void pacman1() {
for (int i = 5; i <= 10; i++) {
leds[XY(1, i)] = CRGB(255, 255, 0); leds[XY(14, i)] = CRGB(255, 255, 0); }
for (int i = 3; i <= 12; i++) { leds[XY(2, i)] = CRGB(255, 255, 0); leds[XY(13, i)] = CRGB(255, 255, 0); }
for (int i = 2; i <= 13; i++) { leds[XY(3, i)] = CRGB(255, 255, 0); leds[XY(4, i)] = CRGB(255, 255, 0); leds[XY(11, i)] = CRGB(255, 255, 0); leds[XY(12, i)] = CRGB(255, 255, 0); }
for (int i = 1; i <= 14; i++) { leds[XY(5, i)] = CRGB(255, 255, 0); leds[XY(6, i)] = CRGB(255, 255, 0); leds[XY(7, i)] = CRGB(255, 255, 0); leds[XY(8, i)] = CRGB(255, 255, 0); leds[XY(9, i)] = CRGB(255, 255, 0); leds[XY(10, i)] = CRGB(255, 255, 0); }
}
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

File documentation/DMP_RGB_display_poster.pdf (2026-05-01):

# Radim Žežulka E4 - Aplikace Mikrokontroléru

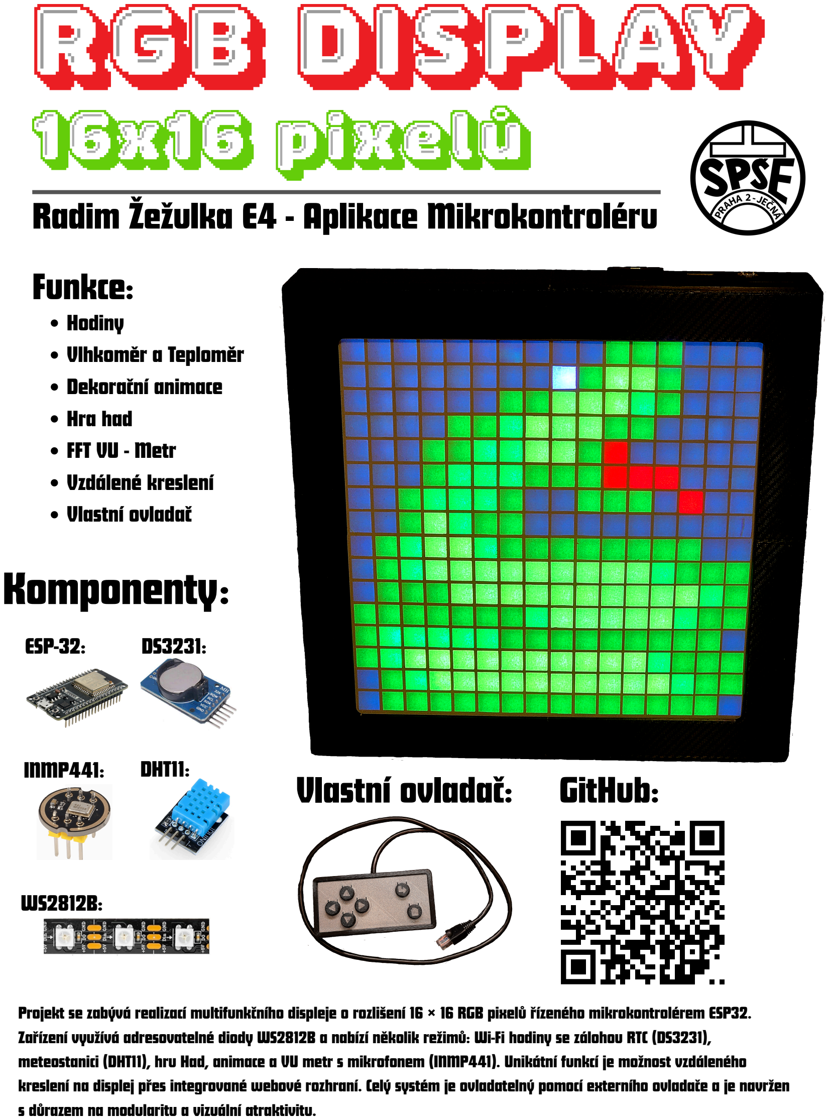
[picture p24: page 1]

## WS2812B:

# Funkce:

Projekt se zabývá realizací multifunkčního displeje o rozlišení 16 × 16 RGB pixelů řízeného mikrokontrolérem ESP32. Zařízení využívá adresovatelné diody WS2812B a nabízí několik režimů: Wi-Fi hodiny se zálohou RTC (DS3231), meteostanici (DHT11), hru Had, animace a VU metr s mikrofonem (INMP441). Unikátní funkcí je možnost vzdáleného kreslení na displej přes integrované webové rozhraní. Celý systém je ovladatelný pomocí externího ovladače a je navržen s důrazem na modularitu a vizuální atraktivitu.

# Vlastní ovladač: GitHub:

# Komponenty:

ESP-32: | DS3231:
INMP441: | DHT11:
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

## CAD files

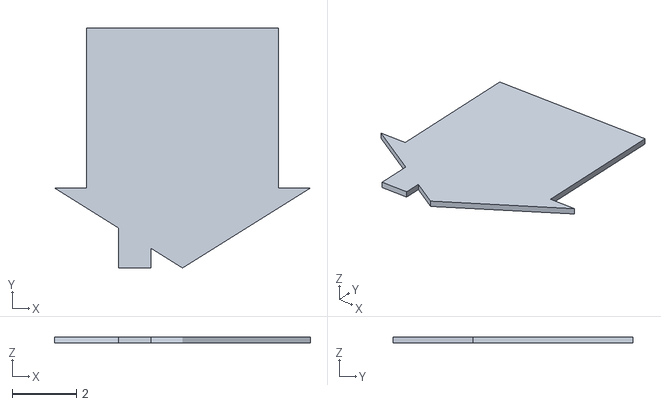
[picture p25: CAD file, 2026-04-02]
3D models/button 3 symbol.stl
8.00 x 7.50 x 0.2

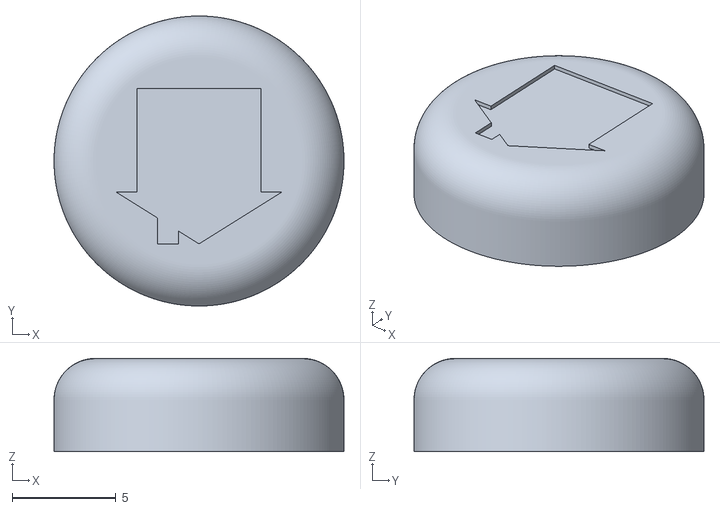
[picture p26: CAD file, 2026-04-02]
3D models/button 3.stl
14.0 x 14.0 x 4.50

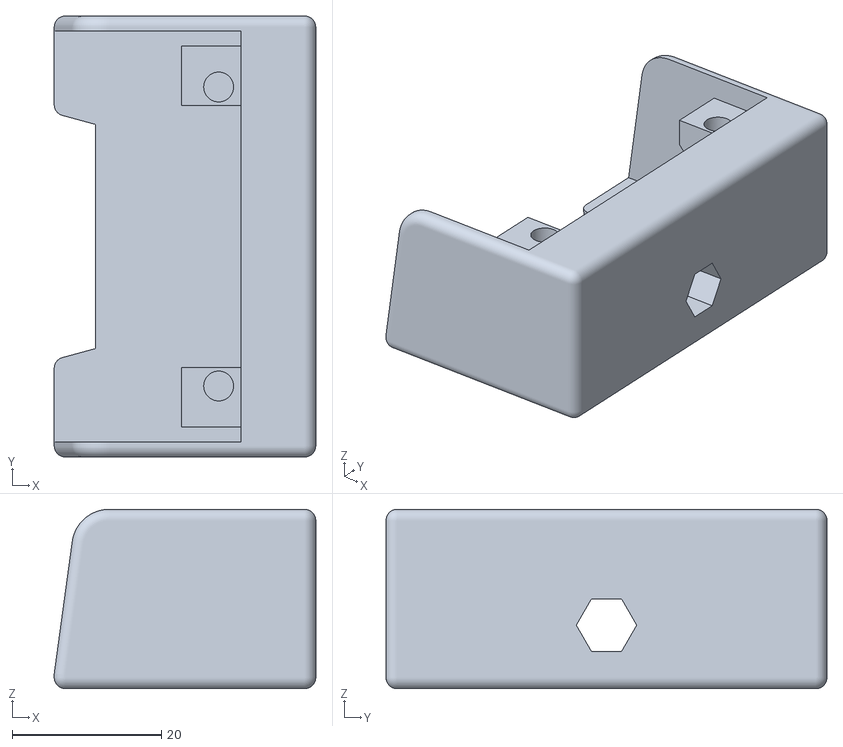
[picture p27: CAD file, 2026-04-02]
3D models/power suply 1.stl
35.0 x 59.0 x 24.0

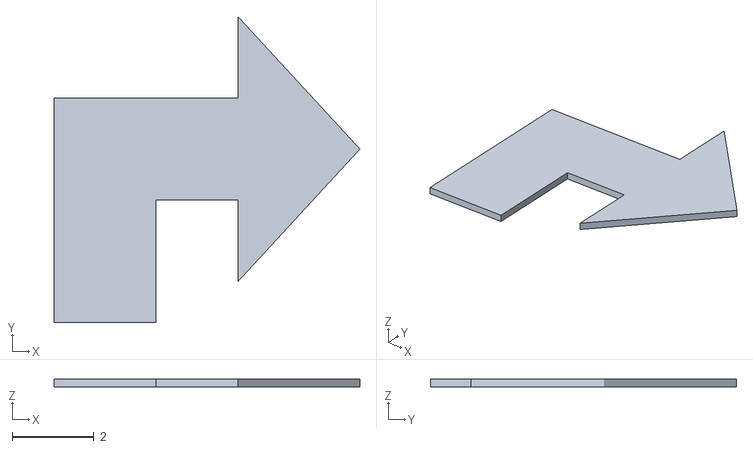
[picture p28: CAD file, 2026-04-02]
3D models/button 2 symbol.stl
7.49 x 7.50 x 0.2

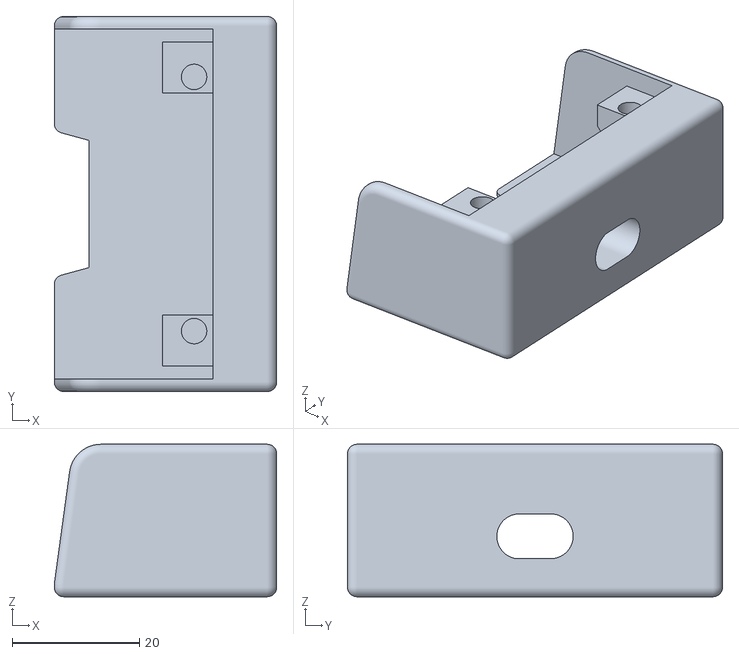
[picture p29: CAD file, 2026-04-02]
3D models/power suply 2.stl
35.0 x 59.0 x 24.0

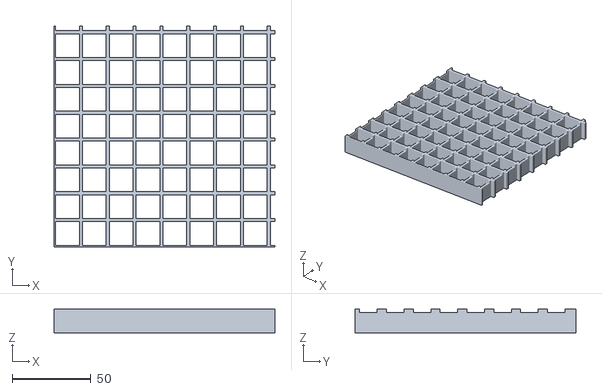
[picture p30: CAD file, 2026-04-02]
3D models/grid 2.stl
140.0 x 140.0 x 15.0

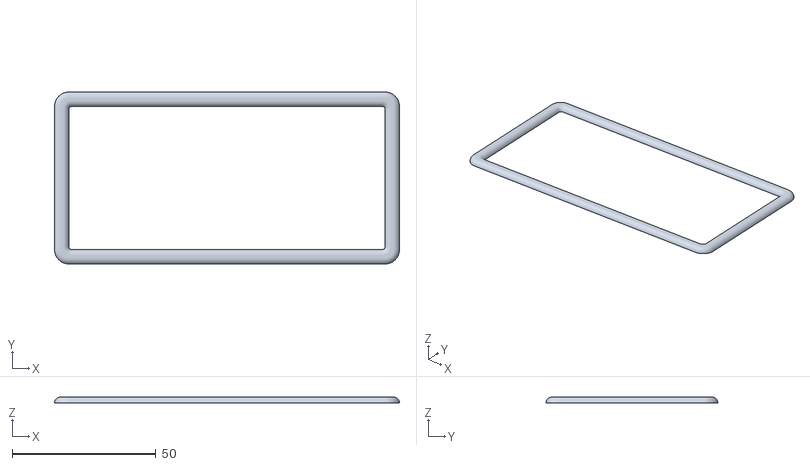
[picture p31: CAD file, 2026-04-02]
3D models/controller 3.stl
120.0 x 59.8 x 2.00

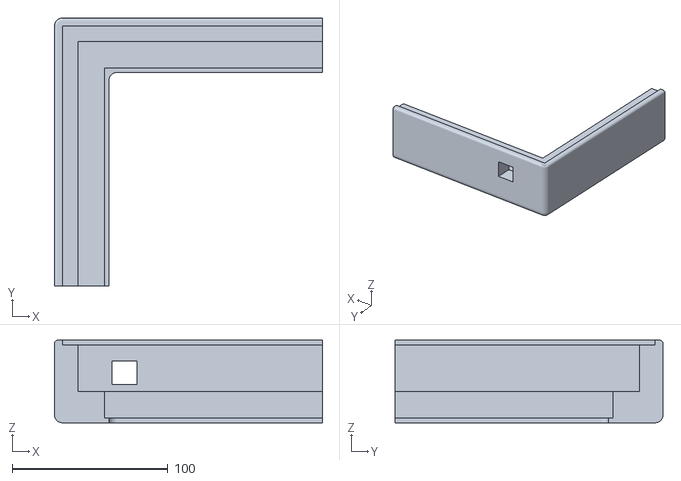
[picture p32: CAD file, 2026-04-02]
3D models/box 3.stl
172.0 x 172.0 x 53.0

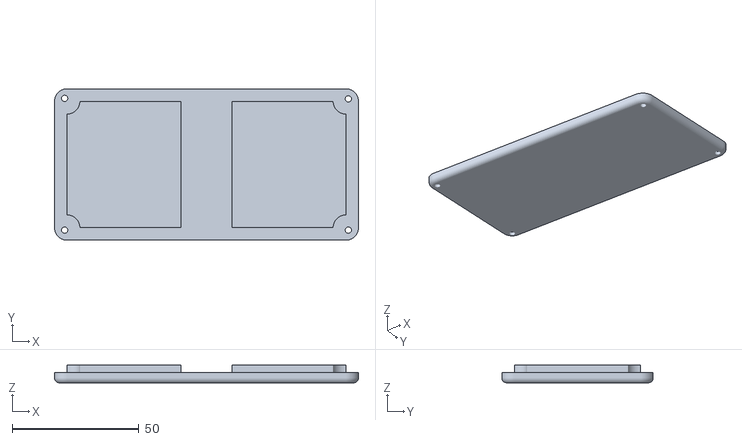
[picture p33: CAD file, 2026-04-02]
3D models/controller 2.stl
120.0 x 59.8 x 7.00

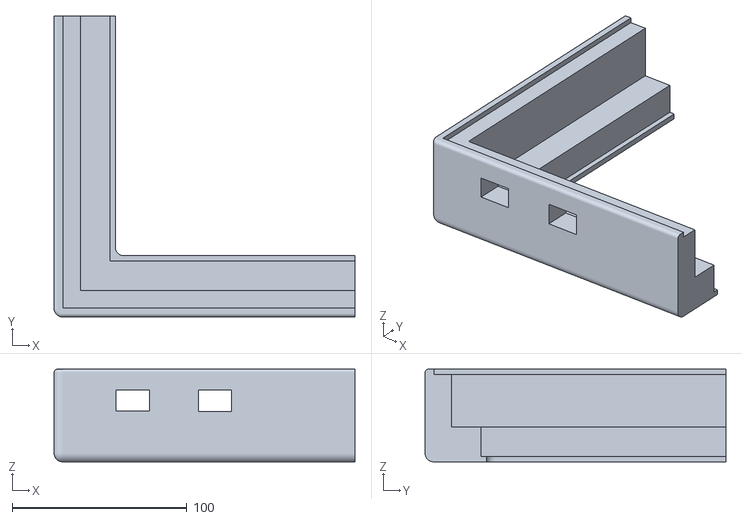
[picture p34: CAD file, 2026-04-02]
3D models/box 4.stl
172.0 x 172.0 x 53.0

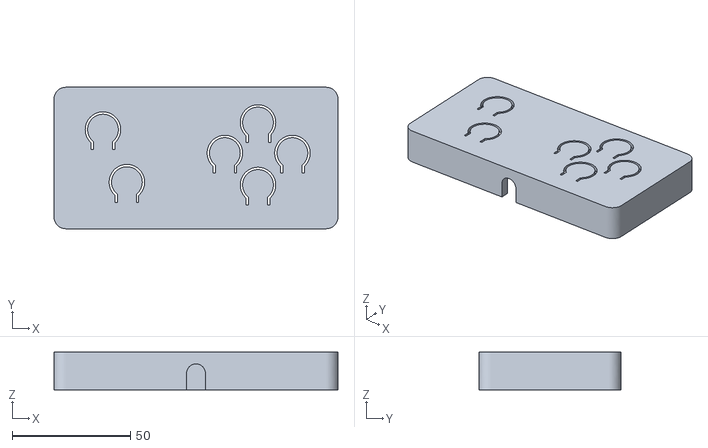
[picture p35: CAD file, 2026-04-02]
3D models/controller 1.stl
120.0 x 59.8 x 16.0

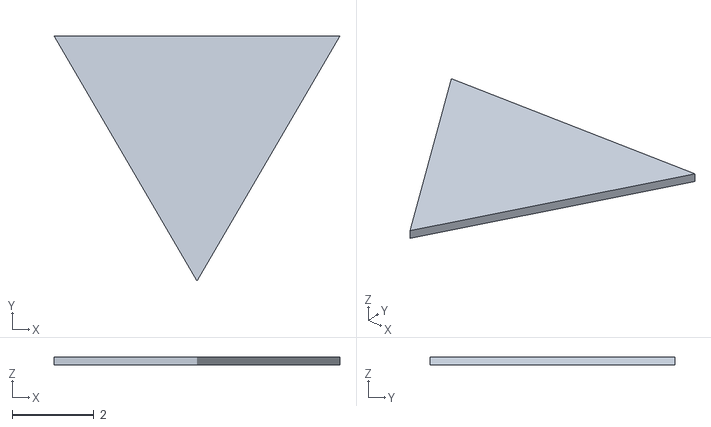
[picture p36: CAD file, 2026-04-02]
3D models/button 1 symbol.stl
7.00 x 6.00 x 0.2

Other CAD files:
3D models/button 2.stl
3D models/box 2.stl
3D models/grid 4.stl
3D models/grid 1.stl
3D models/box 1.stl
3D models/grid 3.stl
3D models/button 1.stl
